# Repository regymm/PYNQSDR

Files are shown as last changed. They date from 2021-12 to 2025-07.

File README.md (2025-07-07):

## PYNQSDR

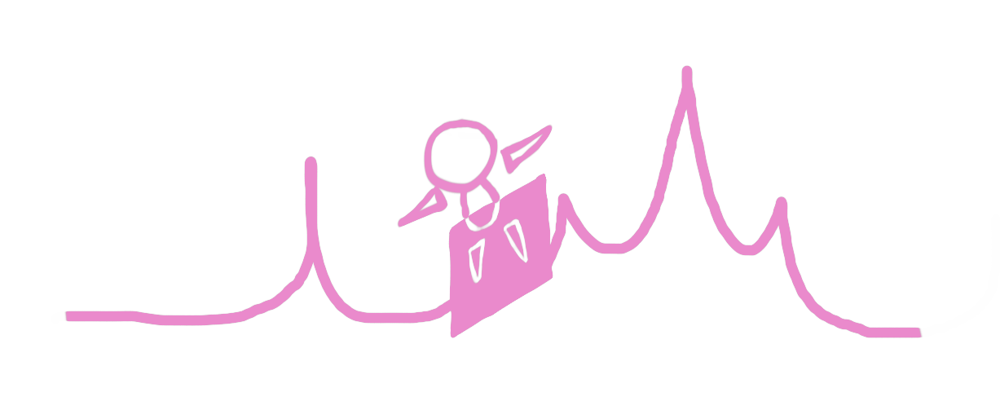
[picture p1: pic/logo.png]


### 🚀　**We're launching! Follow the updates on [Crowd Supply](https://www.crowdsupply.com/xtal-hart-tech/pynqsdr-hat)!**　🚀

PYNQ-Z1 + AD936X SDR platform and more. Openwifi & PlutoSDR capable. 

[KiCad files](./kicad) **|** [Design & future plan](Design.md) **|** [Talk on FOSDEM 2022](https://fosdem.org/2022/schedule/event/openwifipynqz1/) [Slides](doc/openwifi_pynqz1.pdf) **|** [Blog TBD] **|** [Quick start](Quickstart.md) **|** [EBAZSDR TBD]

**Boards are now for sale! Visit my store at [regymm's toy shop](https://regymm.github.io/regymm-toy-shop)!**

This project demonstrated that AD936X chip can combine with low-cost ZYNQ FPGA development boards, especially PYNQ-Z1, and run openwifi without problem. This can potentially become an extremely low-cost openwifi platform. And with extensions removed, you still have a PYNQ capable of any other serious ZYNQ projects. 

Going beyond PYNQ-Z1, this extension board can also combine with other hardware by easy 2-layer conversion board and provide even lower-cost platforms. 

#### Gallery

V1.1 board that works: 

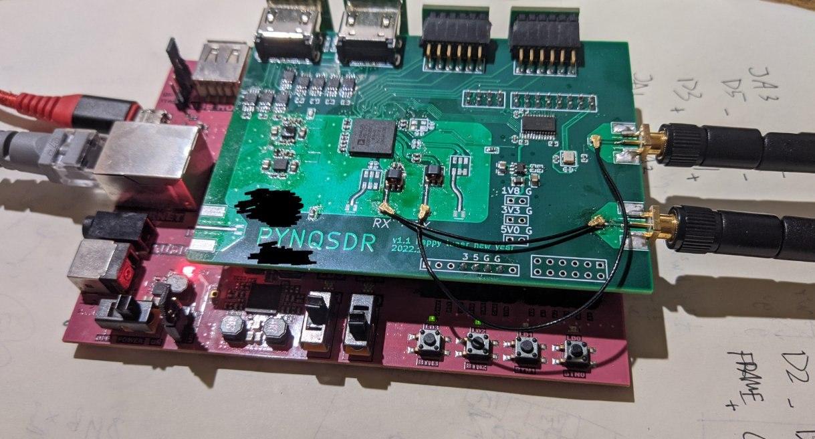
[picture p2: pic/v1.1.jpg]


Openwifi running on PYNQSDR: 

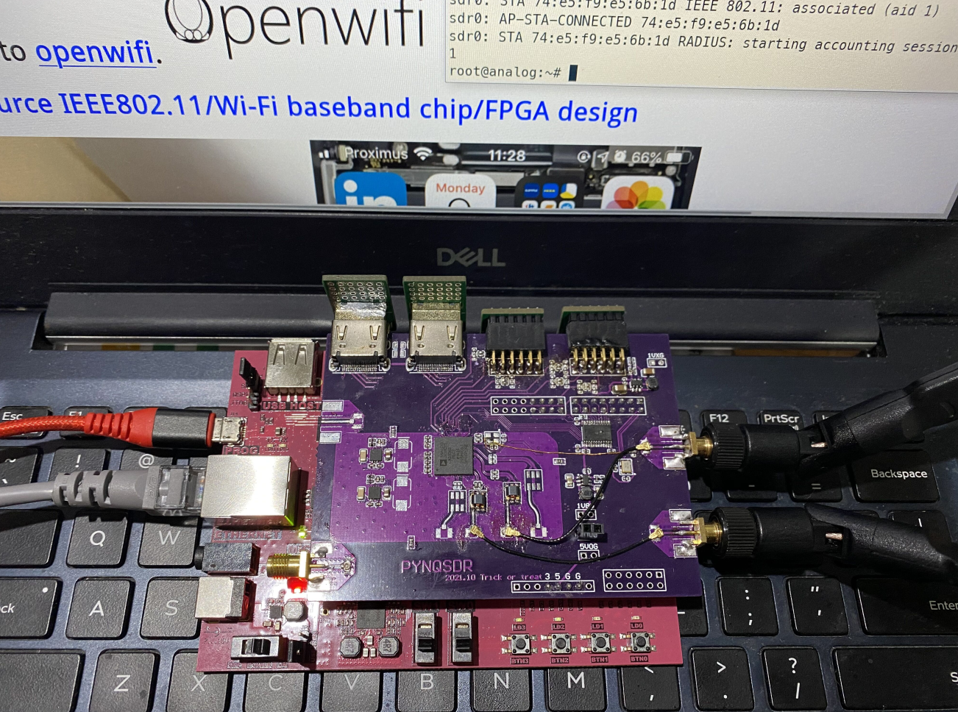
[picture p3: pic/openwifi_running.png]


Board anatomy: 

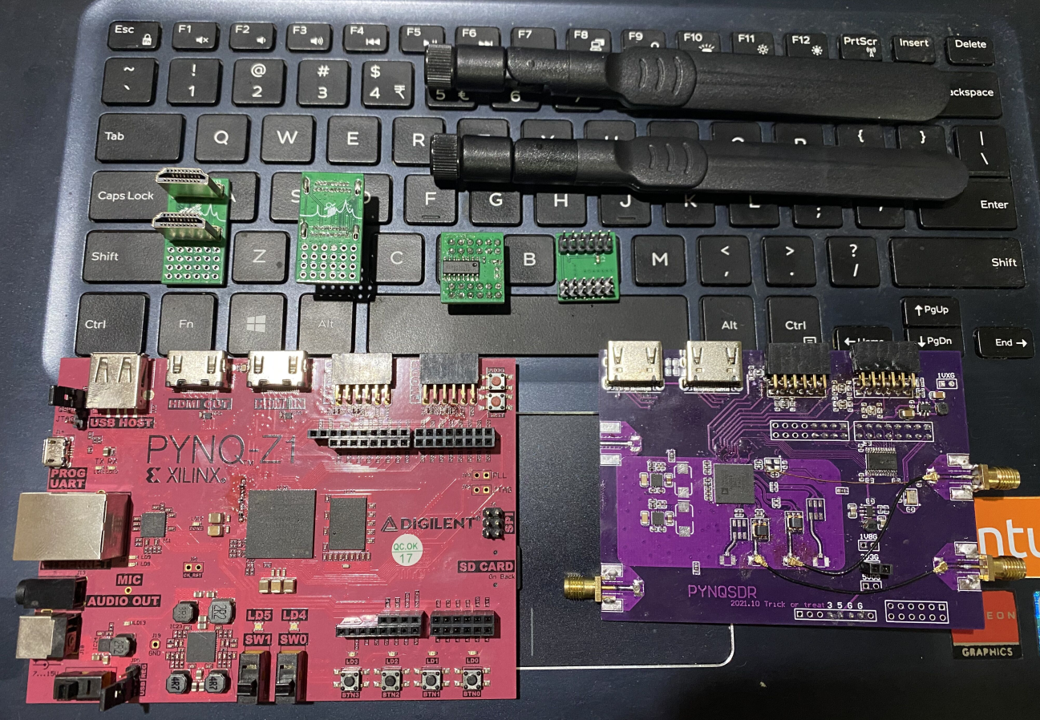
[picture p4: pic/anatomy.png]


#### Credits

Openwifi: https://github.com/open-sdr/openwifi

PlutoSDR: https://github.com/analogdevicesinc/plutosdr-fw

RF frontend PCB design based on https://github.com/kangyuzhe666/ZYNQ7010-7020_AD9363

Many online discussion groups also gave me a lot of help. 

#### License

GPLv3 for all board files. CC BY-SA for blog articles, documents, photos and the logo. Code are coming from different projects and should remain their original licenses.

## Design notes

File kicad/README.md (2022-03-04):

#### PYNQSDR KiCad hardware

pynqsdr: main board, converted from Altium so expect small problems. KiCad nighty required. [Schematics PDF](./pynqsdr.pdf)

br1: HDMI and PMOD direct-connect bridge. 

br2: PMOD bridge with LVDS driver DS90LV047A or SN65LVDS047A. Need 2 of this in initial release and current release(v1.1). 

br3: HDMI bridge with LVDS receiver DS90LVDS048A and PMOD direct-connect. 

br4: HDMI bridge with 4x LVDS to CML translator SN65CML100. Need 2 of this in inital release. 

br5: HDMI bridge with crossing and PMOD direct-connect bridge. 

**v1.1** release requirement: two HDMI direct-connect (br1), two DS90LVDS047A (br2)

**Initial** release requirement: two 4x SN65CML100 (br4), two DS90LVDS047A (br2)

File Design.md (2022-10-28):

#### Design

*Maybe you should first have a look at AD9363 + ZYNQ schematics of [PlutoSDR](https://wiki.analog.com/_media/university/tools/pluto/hacking/plutosdr_schematic_revd_0.1.pdf), [ANTSDR](https://github.com/MicroPhase/antsdr-fw/blob/master/schematic/ant_e310_Public.pdf), and [kangyuzhe666's SDR](https://github.com/kangyuzhe666/ZYNQ7010-7020_AD9363).*

A series of "hacking" is required to get things work. 

- AD936X run on 1.8 V or 2.5 V, while most FPGA boards have VCCIO 3.3 V
  - Use level converters like SN74AX8T245. Changing VCCIO is not plausible because USB and ETH PHY need 3.3 V
- Wiring is both poor and long on FPGA boards
  - So have to use LVDS mode. Openwifi needs LVDS anyways
  - Have to stick to 1RX 1TX. But that's enough for most applications
- But ZYNQ with 3.3 V HP VCCIO can't run LVDS
  - For receiving, HDMI can run TMDS_33. So re-drive using SN65CML100 -- NO change on PYNQ-Z1
    - Can also change 50 R pullup to 100 R series termination and directly receiving LVDS
    - Can also remove 50 R pullup and use DS90LVDS048A receiver
  - For sending, I use single-ended output on FPGA, and convert these to LVDS using DS90LVDS047
- PMOD can't run high speed
  - Yet it can run at 80 MHz (40 M sampling rate 1rx-1tx), enough for openwifi, dump1090, and everything else I tried
  - Optionally remove TVS diodes and 200 ohm series resistors, can run at 120 MHz (~61.44 M sampling rate 1rx-1tx)
- Board shape is strange...
  - Small connectors on PMOD/HDMI side is required
  - I'm worried about mechanical strains caused by HDMI bridges, so using short HDMI cables is being considered. 
- Hand-solder BGA?
  - Heatgun, soldering iron, solder paste, flux are enough, it's really not that hard
  - **warning**: Boards after SMT assembly will suffer oxidation when re-flowing, so ordering SMT assembly w/o the BGA chip then manually solder the BGA may not work well

#### Future plan

V1.2 seems good and will be for sale soon. Another batch(v1.2.1) with minor modification will come soon. 

...

Another 5 fabricated and proved to be fine. Another batch(v1.2) coming soon. 

...

Boards version 1.1 have been made and manually assembled using 1.0's material. It works fine, so another batch of 5 will be made in late Feb. 2022. 

...

Boards version 1.0 suffered BGA soldering problems because they have been re-flowed during STM assembly. 

...

Since I'm confident unmodified PYNQ-Z1 can make it, board version 1.0 will be designed and sent to fabrication and SMT assembly before Dec 31, 2021. 5 boards are to be made. 

If the 5 boards turn to be OK, more will be coming. 

---

Design "explained"(initial testing version, **deprecated**):

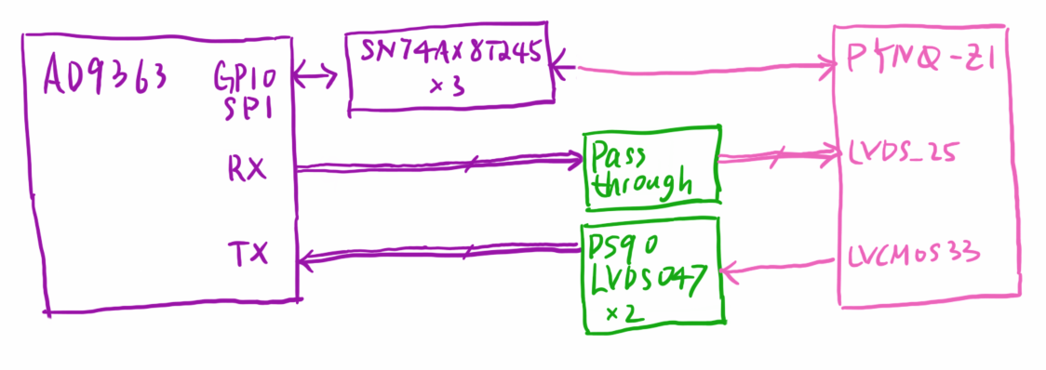
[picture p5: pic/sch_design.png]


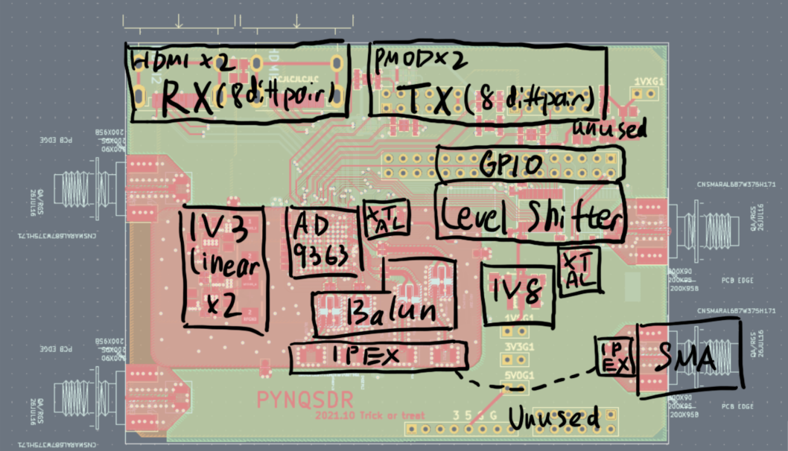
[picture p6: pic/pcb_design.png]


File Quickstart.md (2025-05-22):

### PYNQSDR Quick Start

#### Pre-built images

Currently hosted on my website http://152.70.101.209/

#### Board 

Plug extension boards together, make sure the PMOD plugins are in correct direction -- the 3V3/GND is on the left and IC is on the right: 

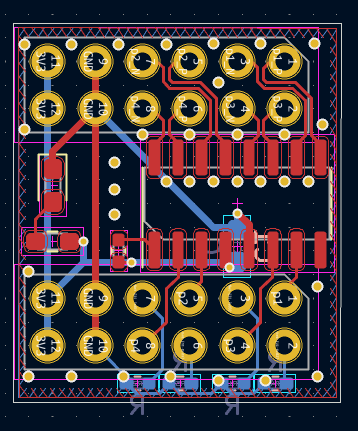
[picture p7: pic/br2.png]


Setup PYNQ-Z1 jumpers to boot from SD card. Use a stable power supply and avoid using USB hubs. Use a good ethernet cable. 

#### Firmware

SD card's boot partition contains boot files, for PlutoSDR, put these into root directory:

```
uEnv.txt -- u-boot loading script
boot.bin -- ZYNQ FSBL including bitstream
uImage -- Linux kernel
devicetree.dtb -- Linux device tree
uramdisk.image.gz -- Linux root directory
```

For openwifi(all of these are different from the Pluto ones!): 

```
uEnv.txt
boot.bin
uImage
devicetree.bin
```

#### Power on

Turn on the power, you'll see the red power LED on -- if this doesn't happen, immediately power off and check your board -- there's probably a short. After ~0.5s LD0-LD3 will have some action after bitstream is loaded. PlutoSDR: among the 4 green LEDs, some is brightly on. Openwifi: some are slightly on(as a simple check, don't rely on this). 

#### Connect

*Pluto*

Linux terminal on USB serial port 115200 baud, root password is `analog`. Board IP will be 192.168.1.10 so set host IP to 192.168.1.2 or so. 

*Openwifi*

Set host ethernet IP to 192.168.10.1, board IP will be 192.168.10.122, ssh into board, username: root, password: `openwifi`. USB serial port has early boot message but will stop after kernel booting(to be solved) so use SSH. 

It's recommended to assign 2 IP addresses(192.168.10.1 and 192.168.1.2 at the same time) to a spare ethernet port. 

#### Pluto

This blog for setup. 

https://regymm.github.io/MyBlog/experience/2022/01/13/plutosdr-setup.html

Since ILA(Vivado internal logic analyzer) corresponding to the pre-built firmware is also included in the downloadable Vivado project, you can open hardware manager in Vivado, the ILA will automatically pop up. 

#### Openwifi 

Manually tune RX/TX: 

```
~/tune.sh
```

`dmesg` to check tune OK: 

```
SAMPL CLK: 40000000 tuning: RX
  0:1:2:3:4:5:6:7:8:9:a:b:c:d:e:f:
0:o o o o o o o o O o o o o o o o 
1:o o o o o # # # # # # # # # # # 
SAMPL CLK: 40000000 tuning: TX
  0:1:2:3:4:5:6:7:8:9:a:b:c:d:e:f:
0:# # # # # # # # # # # # # # # # 
1:# # # # # # # o o o o O o o o o
```

The script is just: 

```
cd /sys/bus/iio/devices/iio\:device1
echo 40000000 > in_voltage_sampling_frequency

cd /sys/kernel/debug/iio/iio\:device1/
echo 0 > adi,digital-interface-tune-skip-mode 
echo 0 3 > digital_tune

dmesg
```

Start wifi: 

`~/openwifi/fosdem-11ag.sh`

*If you are building firmware youself: my board seems to need 10 dB TX attenuation for best transmission, so `#define AD9361_RADIO_ON_TX_ATT 10000` in sdr.h*

#### Troubleshooting

Just contact me...

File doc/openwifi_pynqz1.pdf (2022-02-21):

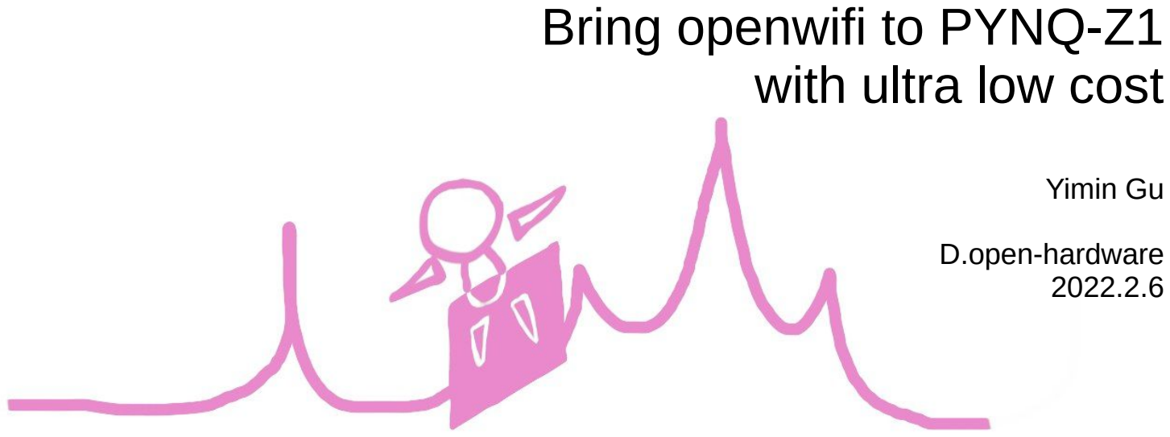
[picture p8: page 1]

## Bring openwifi to PYNQ-Z1

## with ultra low cost

Yimin Gu

D.open-hardware
2022.2.6

## About Me(@regymm)

- Physics undergrad finished last year
- FPGA, PCB design, RISC-V, osdev, scavenge & tweak, NetHack, webcomic…

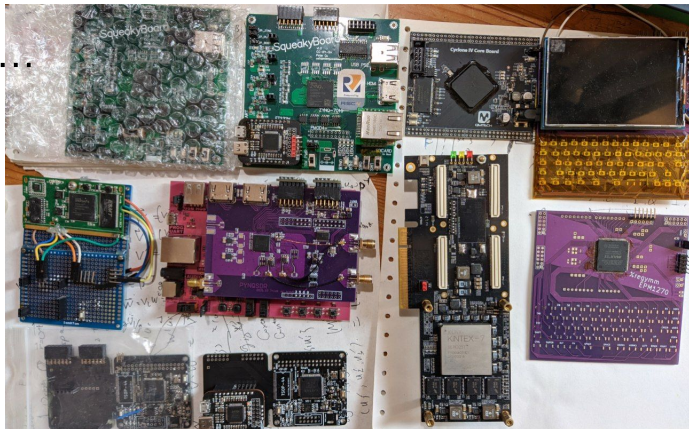
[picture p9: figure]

- SDR: too interesting to ignore…

## Today

- Background that I don’t understand much
- My work: openwifi to PYNQ-Z1
- About “modern” hardware DIY at home

## Background

- Xilinx ZYNQ + ADI AD936X is very capable
- 7010 CLG225 + AD9363 => PlutoSDR
- 7020 CLG400 above + AD9364 => openwifiSp

## Background

- Price is a problem
– | Zedboard + FMCOMMS3 $1300
– | ADRV9364-Z7020 + Carrier $800
– | ANTSDR E310 $300
– | PlutoSDR $150

## PYNQSDR

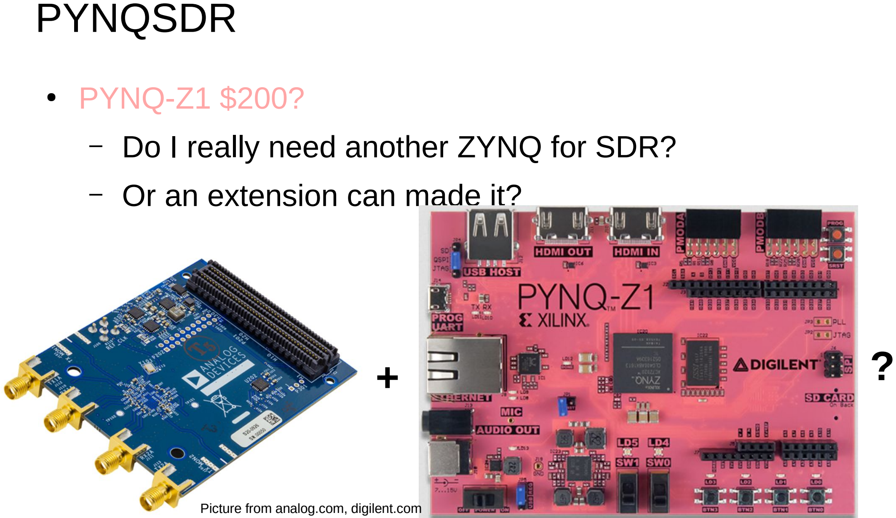
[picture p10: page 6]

- PYNQ-Z1 $200?
– | Do I really need another ZYNQ for SDR?
– | Or an extension can made it?
+ | ?

Picture from analog.com, digilent.com

## PYNQSDR

- AD936X requirements
– | ~21 GPIO at 1.8V/2.5V
– | 16 LVDS diffpairs @ ~120 MHz DDR
- What PYNQ-Z1 has
– | ~49 GPIO at 3.3V, poorly routed
– | 2x HDMI, each 4 diffpairs, 50R* pullup terminaion
– | 2x PMOD, each 4 diffpairs w/ 200R* series and ESD diodes*
| *can be removed/hacked but I don’t want to

## PYNQSDR

- AD936X requirements
– | ~21 GPIO at 1.8V/2.5V
– | 16 LVDS diffpairs @ ~40 MHz DDR
- What PYNQ-Z1 has
– | ~49 GPIO at 3.3V, poorly routed
– | 2x HDMI, each 4 diffpairs, 50R* pullup terminaion
– | 2x PMOD, each 4 diffpairs w/ 200R* series and ESD diodes*
| *can be removed/hacked but I don’t want to

3.3V to 1.8V

LVDS to TMDS(FPGA RX)

LVDS to single-ended(TX)

Hack 9363 to 9364 is bad but...

## PYNQSDR

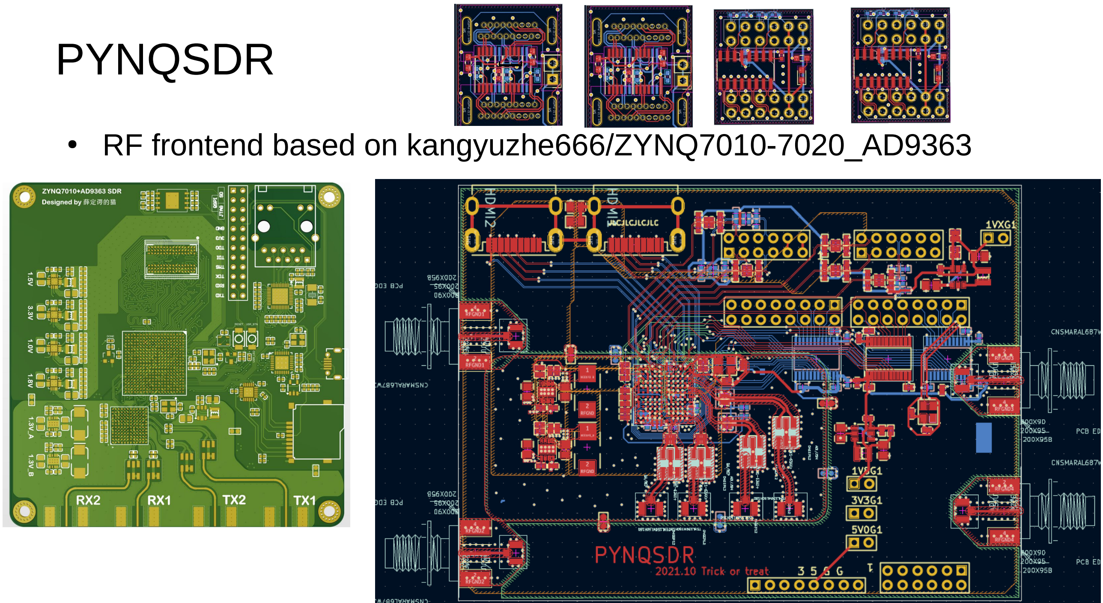
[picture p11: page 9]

- RF frontend based on kangyuzhe666/ZYNQ7010-7020_AD9363

[

## PYNQSDR

- Firmware porting based on ANTSDR

– checklist: adi-hdl(IO, ps7, xdc), u-boot, kernel, dts

- Stick to 1 RX 1TX mode(TX can run ~50 MHz DDR at most)
- … and afaik everything works
– | Openwifi 5G hotspot/client
– | GQRX FM
– | ADS-B

## PYNQSDR

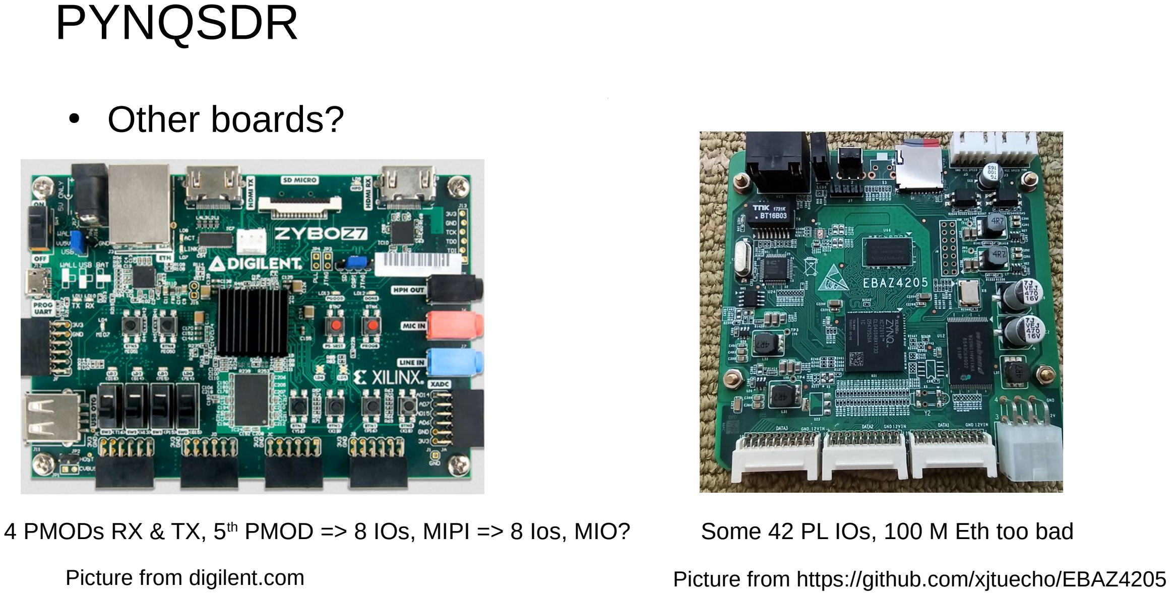
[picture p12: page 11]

- Other boards?

Picture from digilent.com

4 PMODs RX & TX, 5th PMOD => 8 IOs, MIPI => 8 Ios, MIO?

Picture from https://github.com/xjtuecho/EBAZ4205

Some 42 PL IOs, 100 M Eth too bad

## About “modern” HW DIY at home

- Manufacture at JLCPCB/… leaded 4-layer 0.8mm BGA should be affordable
- “Refurbished” chips on Taobao/Aliexpress

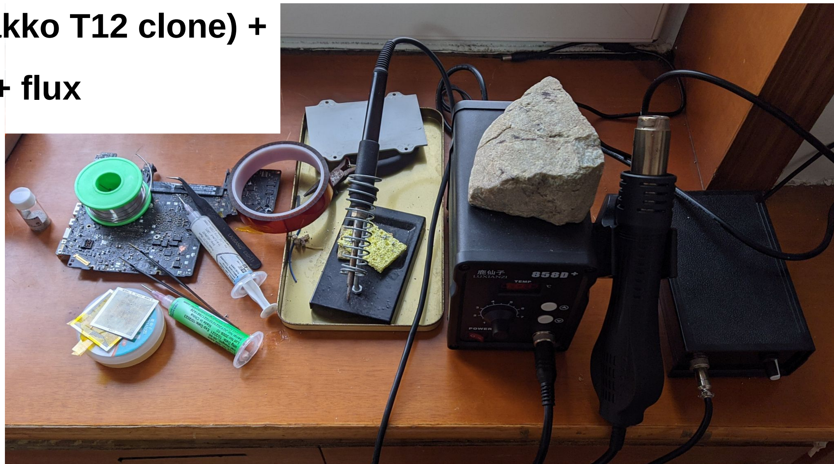
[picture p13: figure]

- Soldering iron(936 or hakko T12 clone) +

heatgun + solder paste + flux

## About “modern” HW DIY at home

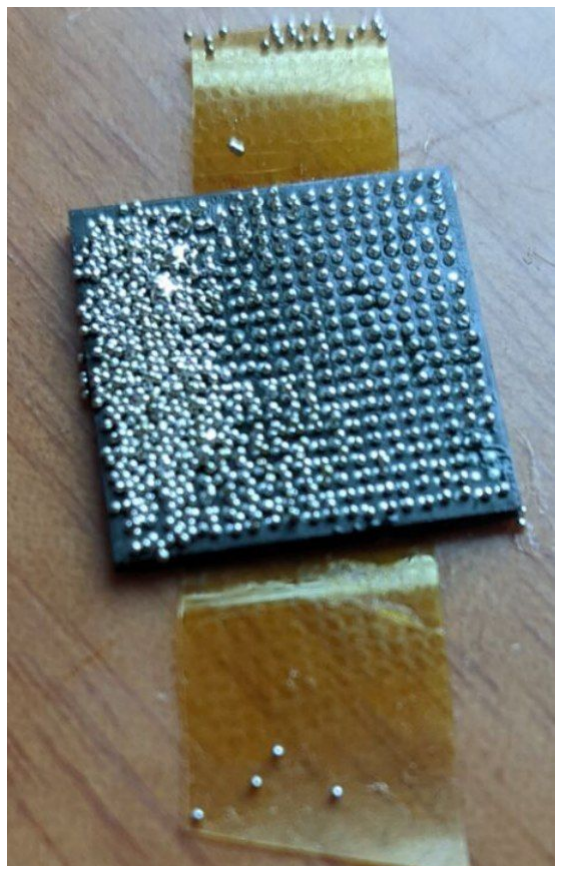
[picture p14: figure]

- BGA?

## Thanks!

- Dr. Jiao’s nice help & invitation to FOSDEM
- kangyuzhe666’s SDR
- Various discussion groups

Q & A

Contact

– | GitHub repo for PYNQSDR: github.com/regymm/PYNQSDR
– | My Twitter: @regymm0
– | My Telegram: @regymm0 Channel: t.me/xtalhart

*For later viewers: it’s recommended to watch the talk, many important stuffs are not shown in this slides

*Proudly made with LibreOffice

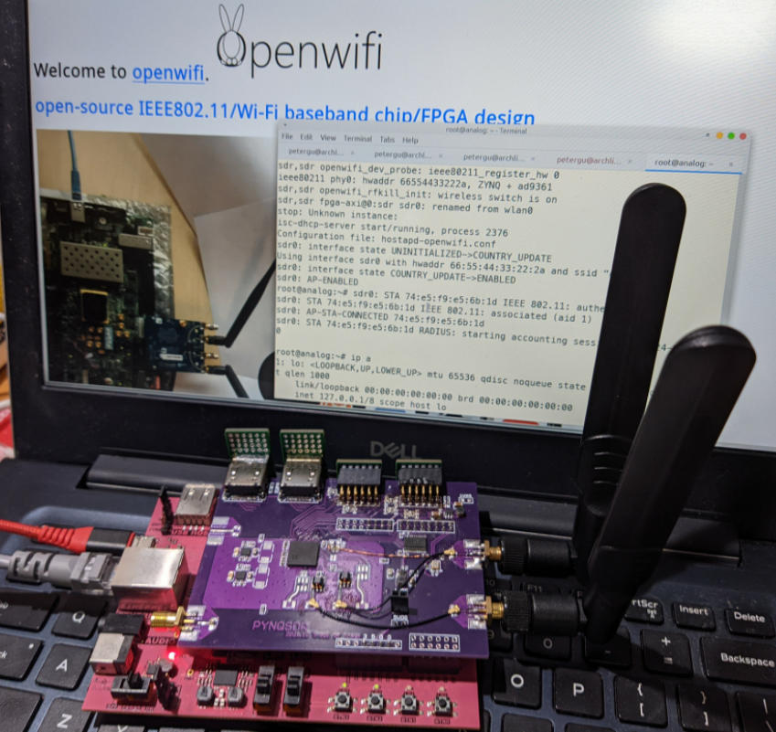
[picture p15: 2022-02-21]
pic/pic2.png

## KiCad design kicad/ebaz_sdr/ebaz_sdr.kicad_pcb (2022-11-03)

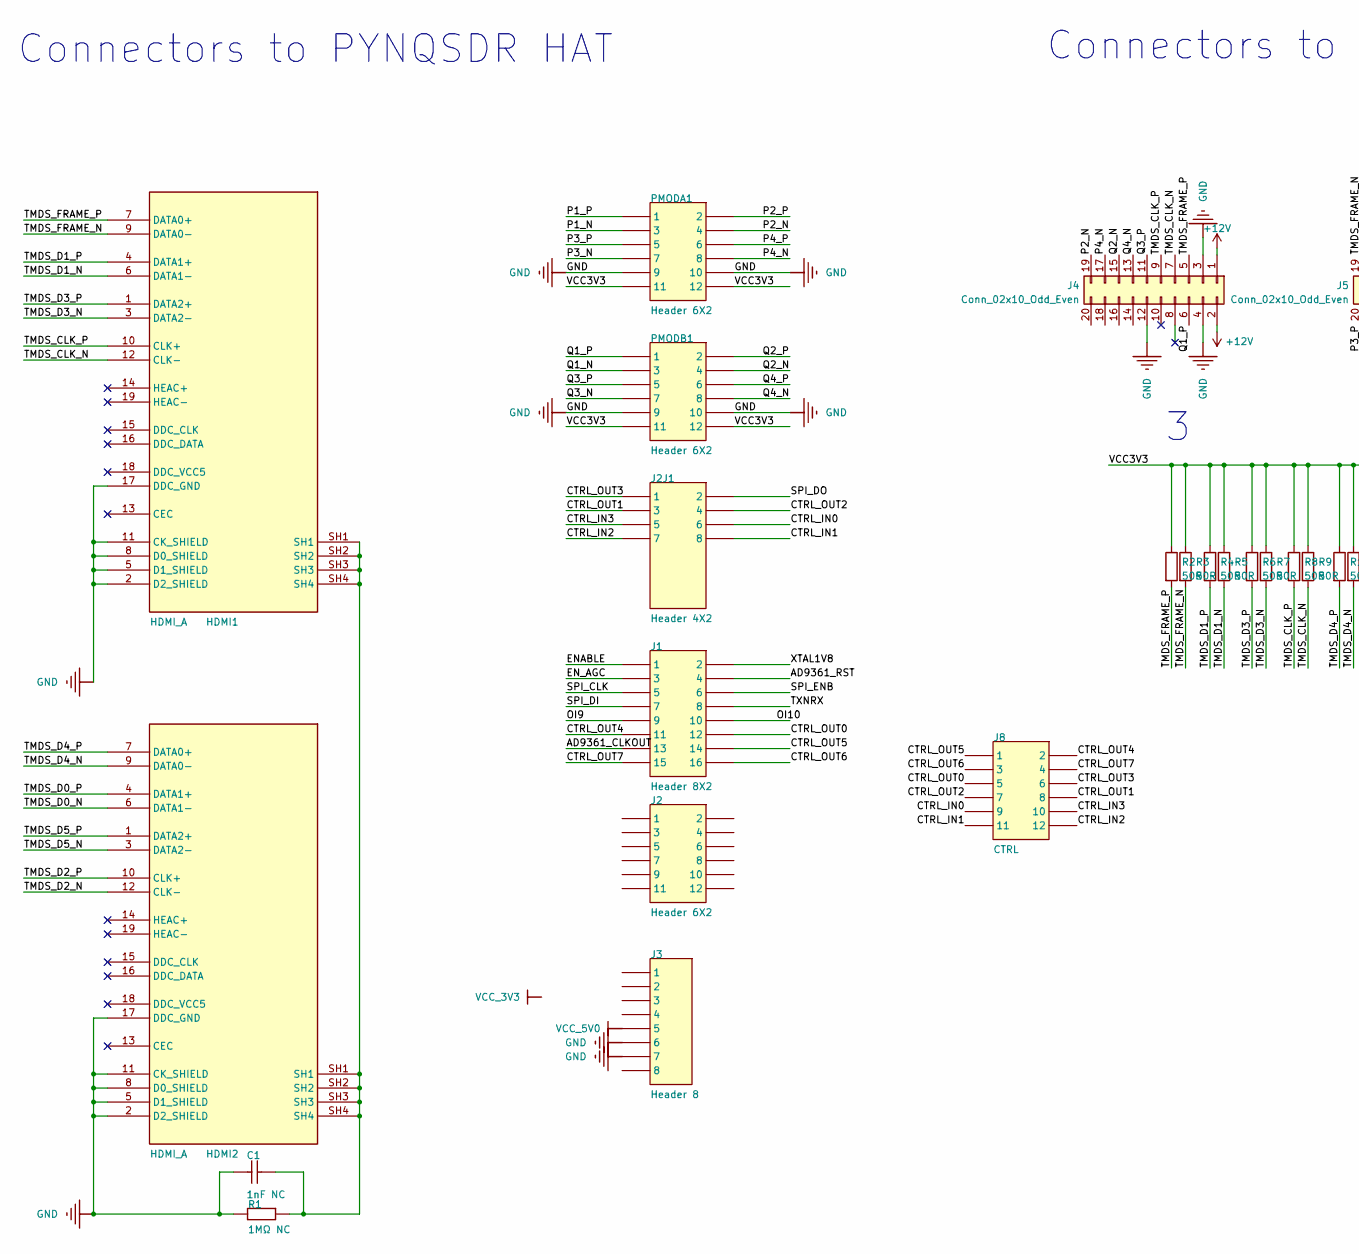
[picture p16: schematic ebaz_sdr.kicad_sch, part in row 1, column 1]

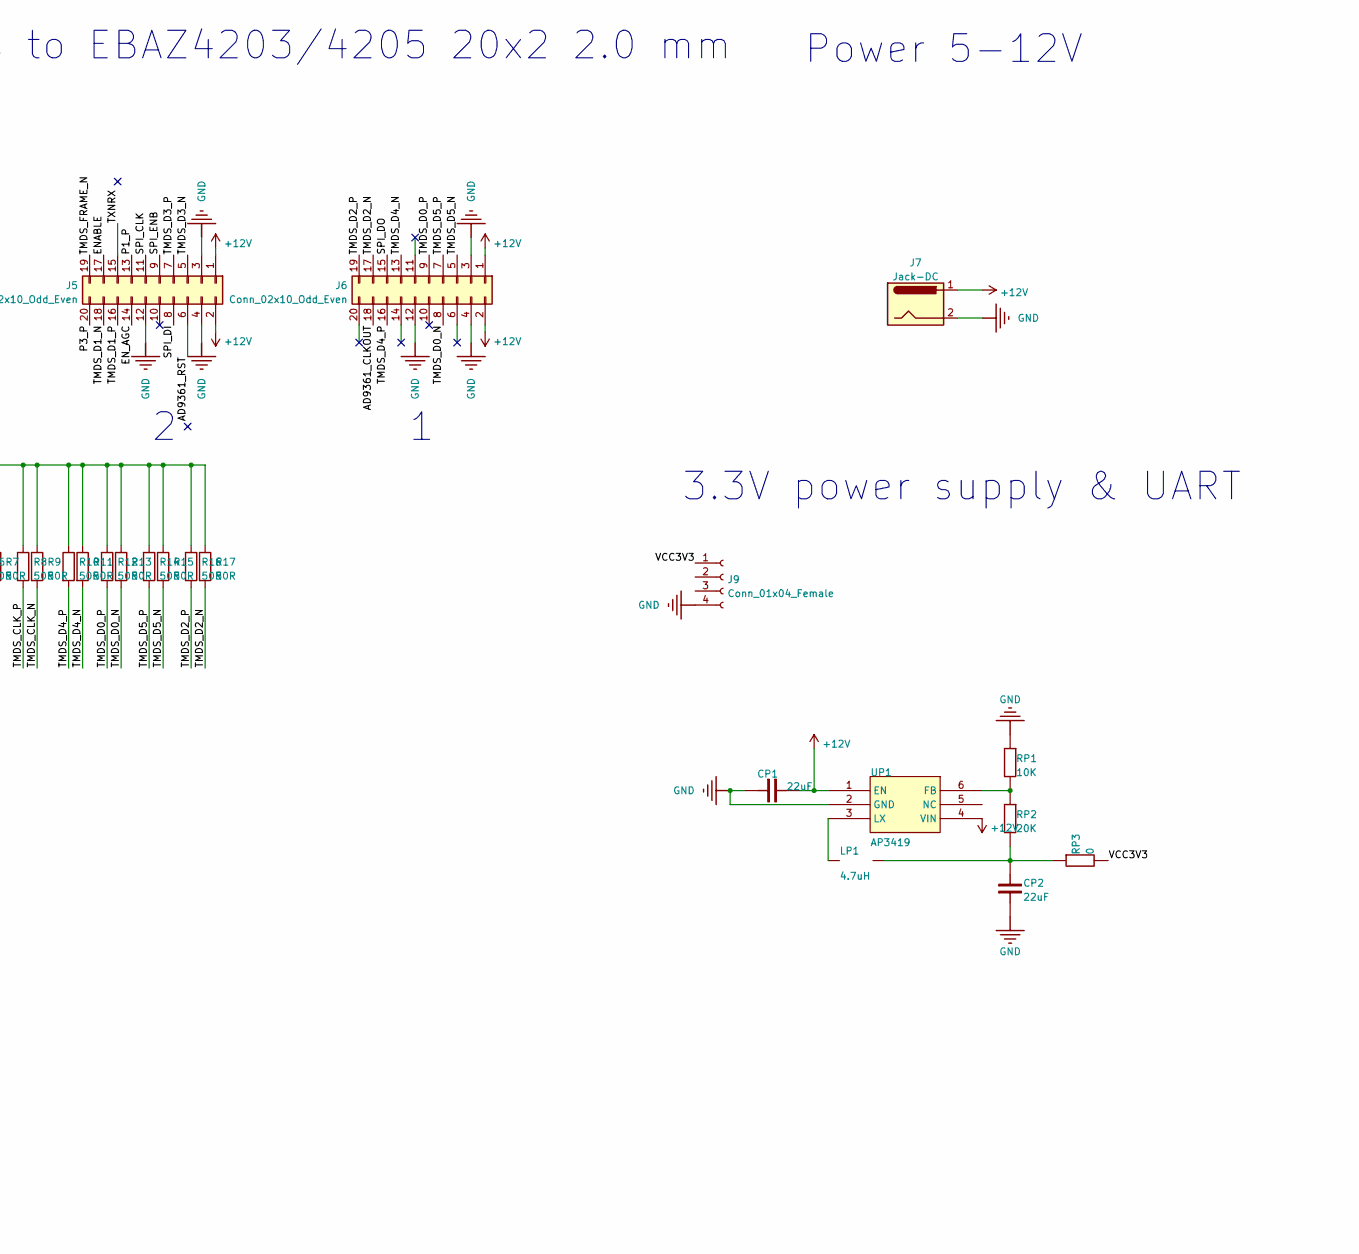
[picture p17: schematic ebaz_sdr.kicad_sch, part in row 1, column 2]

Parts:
C1: 1nF NC; R_0603_1608Metric_Pad0.98x0.95mm_HandSolder
CP1, CP2: 22uF; LC-0805_C
HDMI1, HDMI2: HDMI_A
J1: Header 8X2; HDR2X8
J2: Header 6X2; HDR2X6
J2J1: Header 4X2; HDR2X8
J3: Header 8; HDR1X8
J4, J5, J6: Conn_02x10_Odd_Even; PinSocket_2x10_P2.00mm_Horizontal
J7: Jack-DC; BarrelJack_Wuerth_6941xx301002
J8: CTRL; HDR2X6
J9: Conn_01x04_Female; PinHeader_1x04_P2.54mm_Vertical
LP1: 4.7uH; L1008
PMODA1: Header 6X2; HDR2X6
PMODB1: Header 6X2; HDR2X6
R1: 1MΩ NC; R_0603_1608Metric_Pad0.98x0.95mm_HandSolder
R2, R3, R4, R5, R6, R7, R8, R9, R10, R11, R12, R13, R14, R15, R16, R17: 50R; R_0402_1005Metric_Pad0.72x0.64mm_HandSolder
RP1: 10K; LC-0402_R
RP2: 20K; LC-0402_R
RP3: 0; LC-0402_R
UP1: AP3419

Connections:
+12V: CP1.2, J4.1, J4.2, J5.1, J5.2, J6.1, J6.2, J7.1, UP1.1 (EN), UP1.4 (VIN)
/AD9361_CLKOUT: J1.13, J6.18
/AD9361_RST: J1.4, J5.6
/CTRL_IN0: J2J1.6, J8.9
/CTRL_IN1: J2J1.8, J8.11
/CTRL_IN2: J2J1.7, J8.12
/CTRL_IN3: J2J1.5, J8.10
/CTRL_OUT0: J1.12, J8.5
/CTRL_OUT1: J2J1.3, J8.8
/CTRL_OUT2: J2J1.4, J8.7
/CTRL_OUT3: J2J1.1, J8.6
/CTRL_OUT4: J1.11, J8.2
/CTRL_OUT5: J1.14, J8.1
/CTRL_OUT6: J1.16, J8.3
/CTRL_OUT7: J1.15, J8.4
/ENABLE: J1.1, J5.17
/EN_AGC: J1.3, J5.14
/OI9: J1.9
/OI10: J1.10
/P1_N: PMODA1.3
/P1_P: J5.13, PMODA1.1
/P2_N: J4.19, PMODA1.4
/P2_P: PMODA1.2
/P3_N: PMODA1.7
/P3_P: J5.20, PMODA1.5
/P4_N: J4.17, PMODA1.8
/P4_P: PMODA1.6
/Q1_N: PMODB1.3
/Q1_P: J4.6, PMODB1.1
/Q2_N: J4.15, PMODB1.4
/Q2_P: PMODB1.2
/Q3_N: PMODB1.7
/Q3_P: J4.11, PMODB1.5
/Q4_N: J4.13, PMODB1.8
/Q4_P: PMODB1.6
/SPI_CLK: J1.5, J5.11
/SPI_DI: J1.7, J5.8
/SPI_DO: J2J1.2, J6.15
/SPI_ENB: J1.6, J5.9
/TMDS_CLK_N: HDMI1.12 (CLK-), J4.7, R9.2
/TMDS_CLK_P: HDMI1.10 (CLK+), J4.9, R8.2
/TMDS_D0_N: HDMI2.6 (DATA1-), J6.8, R13.2
/TMDS_D0_P: HDMI2.4 (DATA1+), J6.9, R12.2
/TMDS_D1_N: HDMI1.6 (DATA1-), J5.18, R5.2
/TMDS_D1_P: HDMI1.4 (DATA1+), J5.16, R4.2
/TMDS_D2_N: HDMI2.12 (CLK-), J6.17, R17.2
/TMDS_D2_P: HDMI2.10 (CLK+), J6.19, R16.2
/TMDS_D3_N: HDMI1.3 (DATA2-), J5.5, R7.2
/TMDS_D3_P: HDMI1.1 (DATA2+), J5.7, R6.2
/TMDS_D4_N: HDMI2.9 (DATA0-), J6.13, R11.2
/TMDS_D4_P: HDMI2.7 (DATA0+), J6.16, R10.2
/TMDS_D5_N: HDMI2.3 (DATA2-), J6.5, R15.2
/TMDS_D5_P: HDMI2.1 (DATA2+), J6.7, R14.2
/TMDS_FRAME_N: HDMI1.9 (DATA0-), J5.19, R3.2
/TMDS_FRAME_P: HDMI1.7 (DATA0+), J4.5, R2.2
/TXNRX: J1.8, J5.15
/VCC3V3: J9.1, PMODA1.11, PMODA1.12, PMODB1.11, PMODB1.12, R2.1, R3.1, R4.1, R5.1, R6.1, R7.1, R8.1, R9.1, R10.1, R11.1, R12.1, R13.1, R14.1, R15.1, R16.1, R17.1, RP3.1
/XTAL1V8: J1.2
GND: C1.2, CP1.1, CP2.1, HDMI1.2 (D2_SHIELD), HDMI1.5 (D1_SHIELD), HDMI1.8 (D0_SHIELD), HDMI1.11 (CK_SHIELD), HDMI1.17 (DDC_GND), HDMI2.2 (D2_SHIELD), HDMI2.5 (D1_SHIELD), HDMI2.8 (D0_SHIELD), HDMI2.11 (CK_SHIELD), HDMI2.17 (DDC_GND), J3.6, J3.7, J4.3, J4.4, J4.12, J5.3, J5.4, J5.12, J6.3, J6.4, J6.12, J7.2, J9.4, PMODA1.9, PMODA1.10, PMODB1.9, PMODB1.10, R1.2, RP1.2, UP1.2 (GND)
unnamed: C1.1, HDMI1.SH1, HDMI1.SH2, HDMI1.SH3, HDMI1.SH4, HDMI2.SH1, HDMI2.SH2, HDMI2.SH3, HDMI2.SH4, R1.1
unnamed: CP2.2, LP1.2, RP2.1, RP3.2
unnamed: LP1.1, UP1.3 (LX)
unnamed: RP1.1, RP2.2, UP1.6 (FB)
VCC_5V0: J3.5

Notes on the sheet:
Power 5-12V
Connectors to EBAZ4203/4205 20x2 2.0 mm
Connectors to PYNQSDR HAT
3.3V power supply & UART
3 2 1

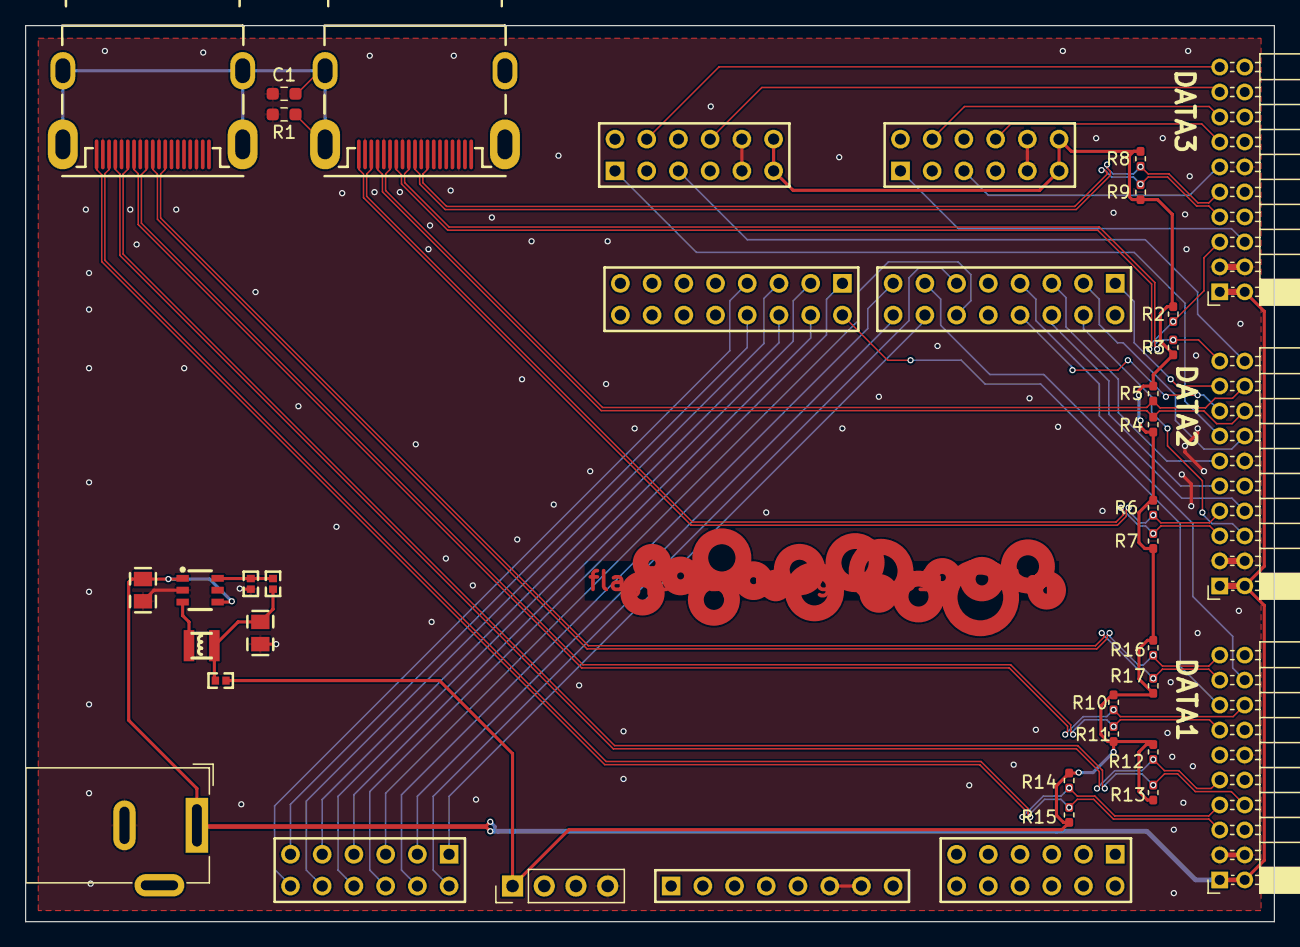
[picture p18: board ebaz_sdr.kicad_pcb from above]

Board: 2 copper layers, 100.0 x 71.8 mm, 39 parts (0 on the bottom side), 52 nets.

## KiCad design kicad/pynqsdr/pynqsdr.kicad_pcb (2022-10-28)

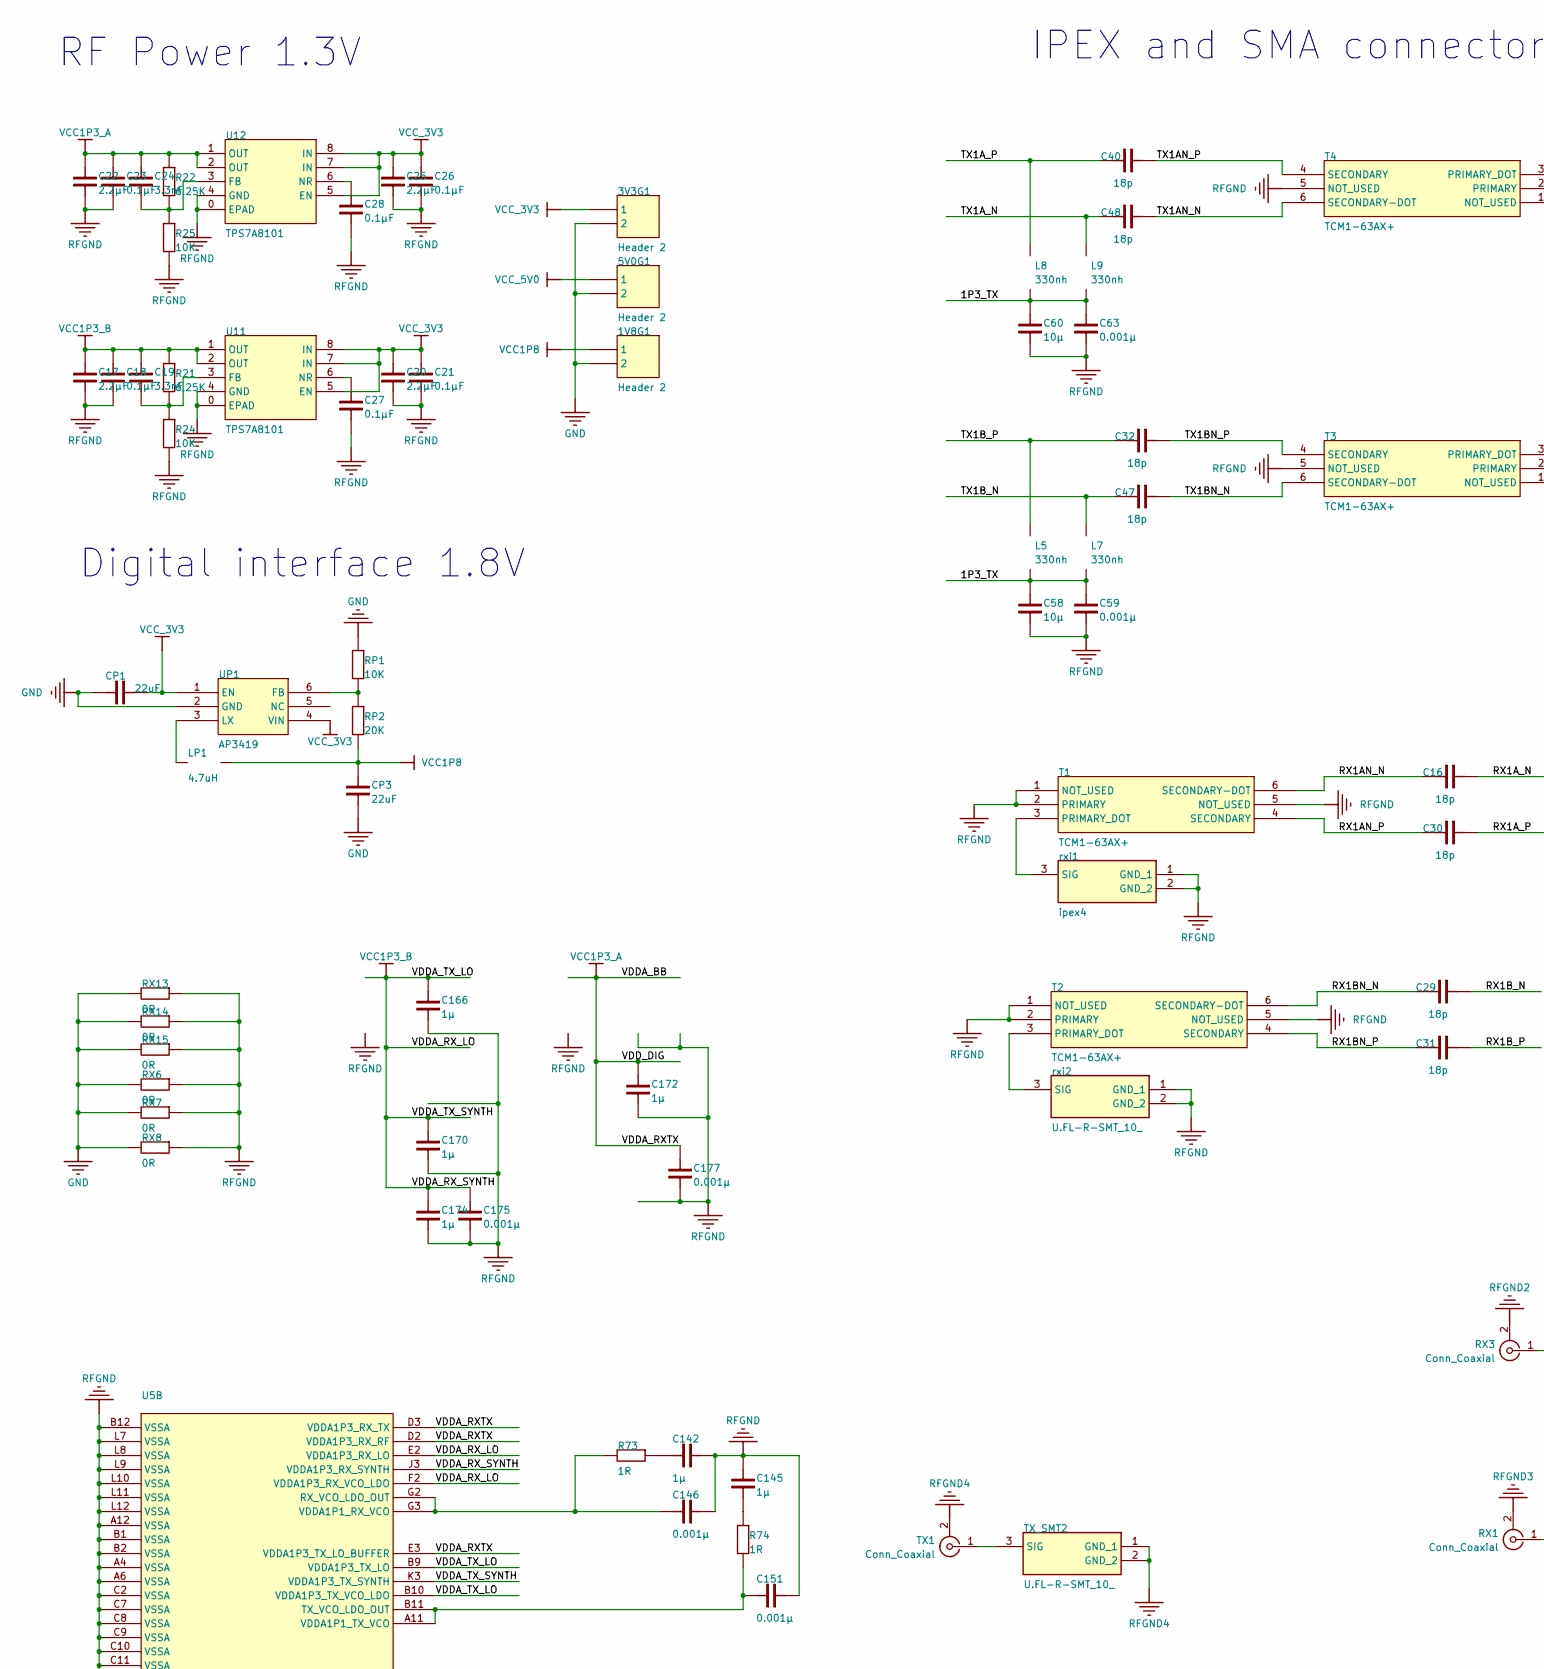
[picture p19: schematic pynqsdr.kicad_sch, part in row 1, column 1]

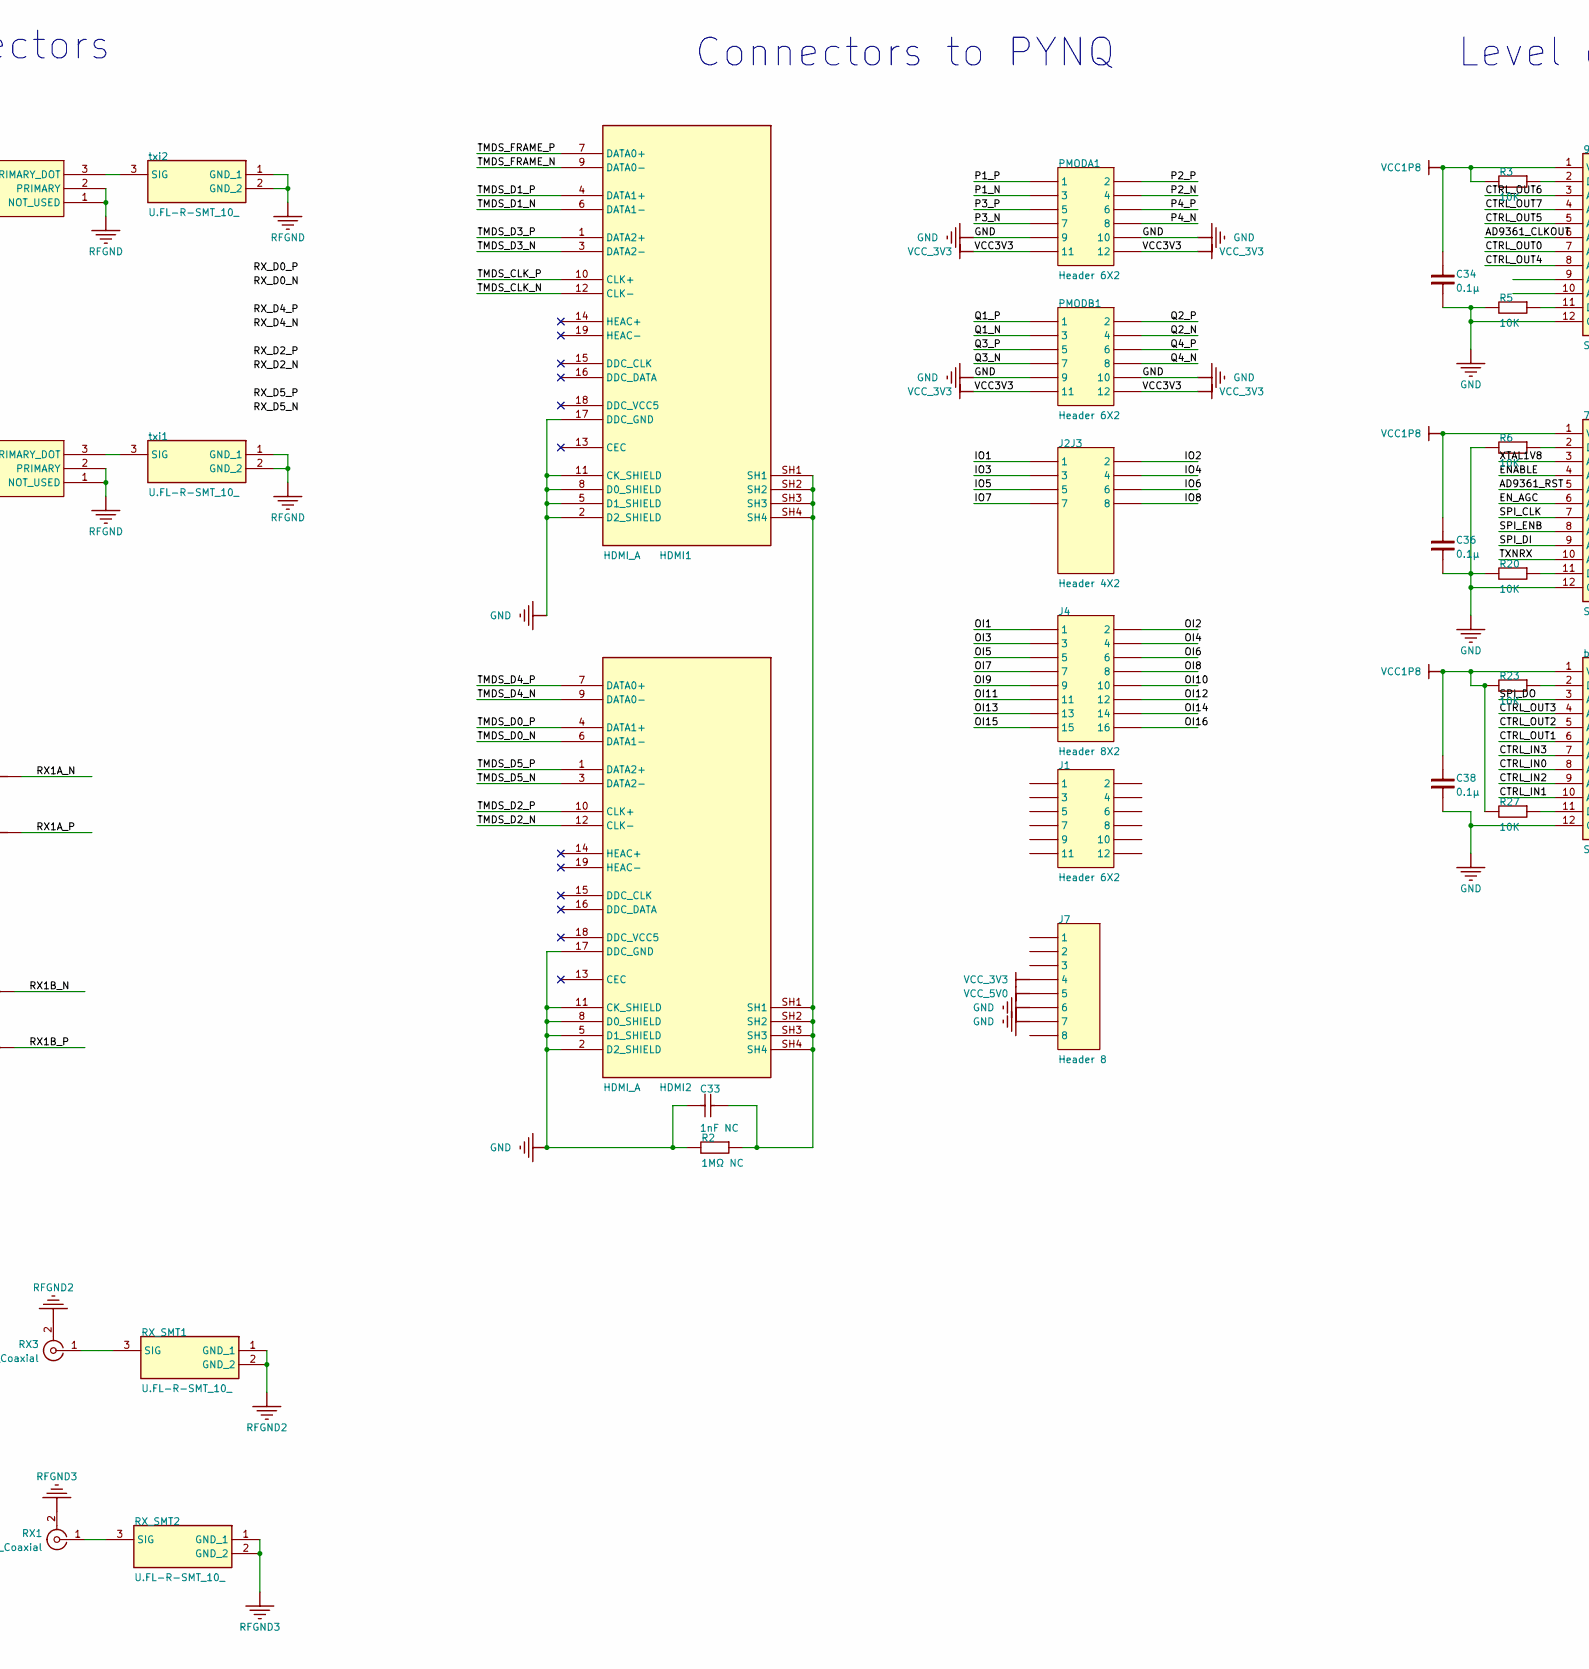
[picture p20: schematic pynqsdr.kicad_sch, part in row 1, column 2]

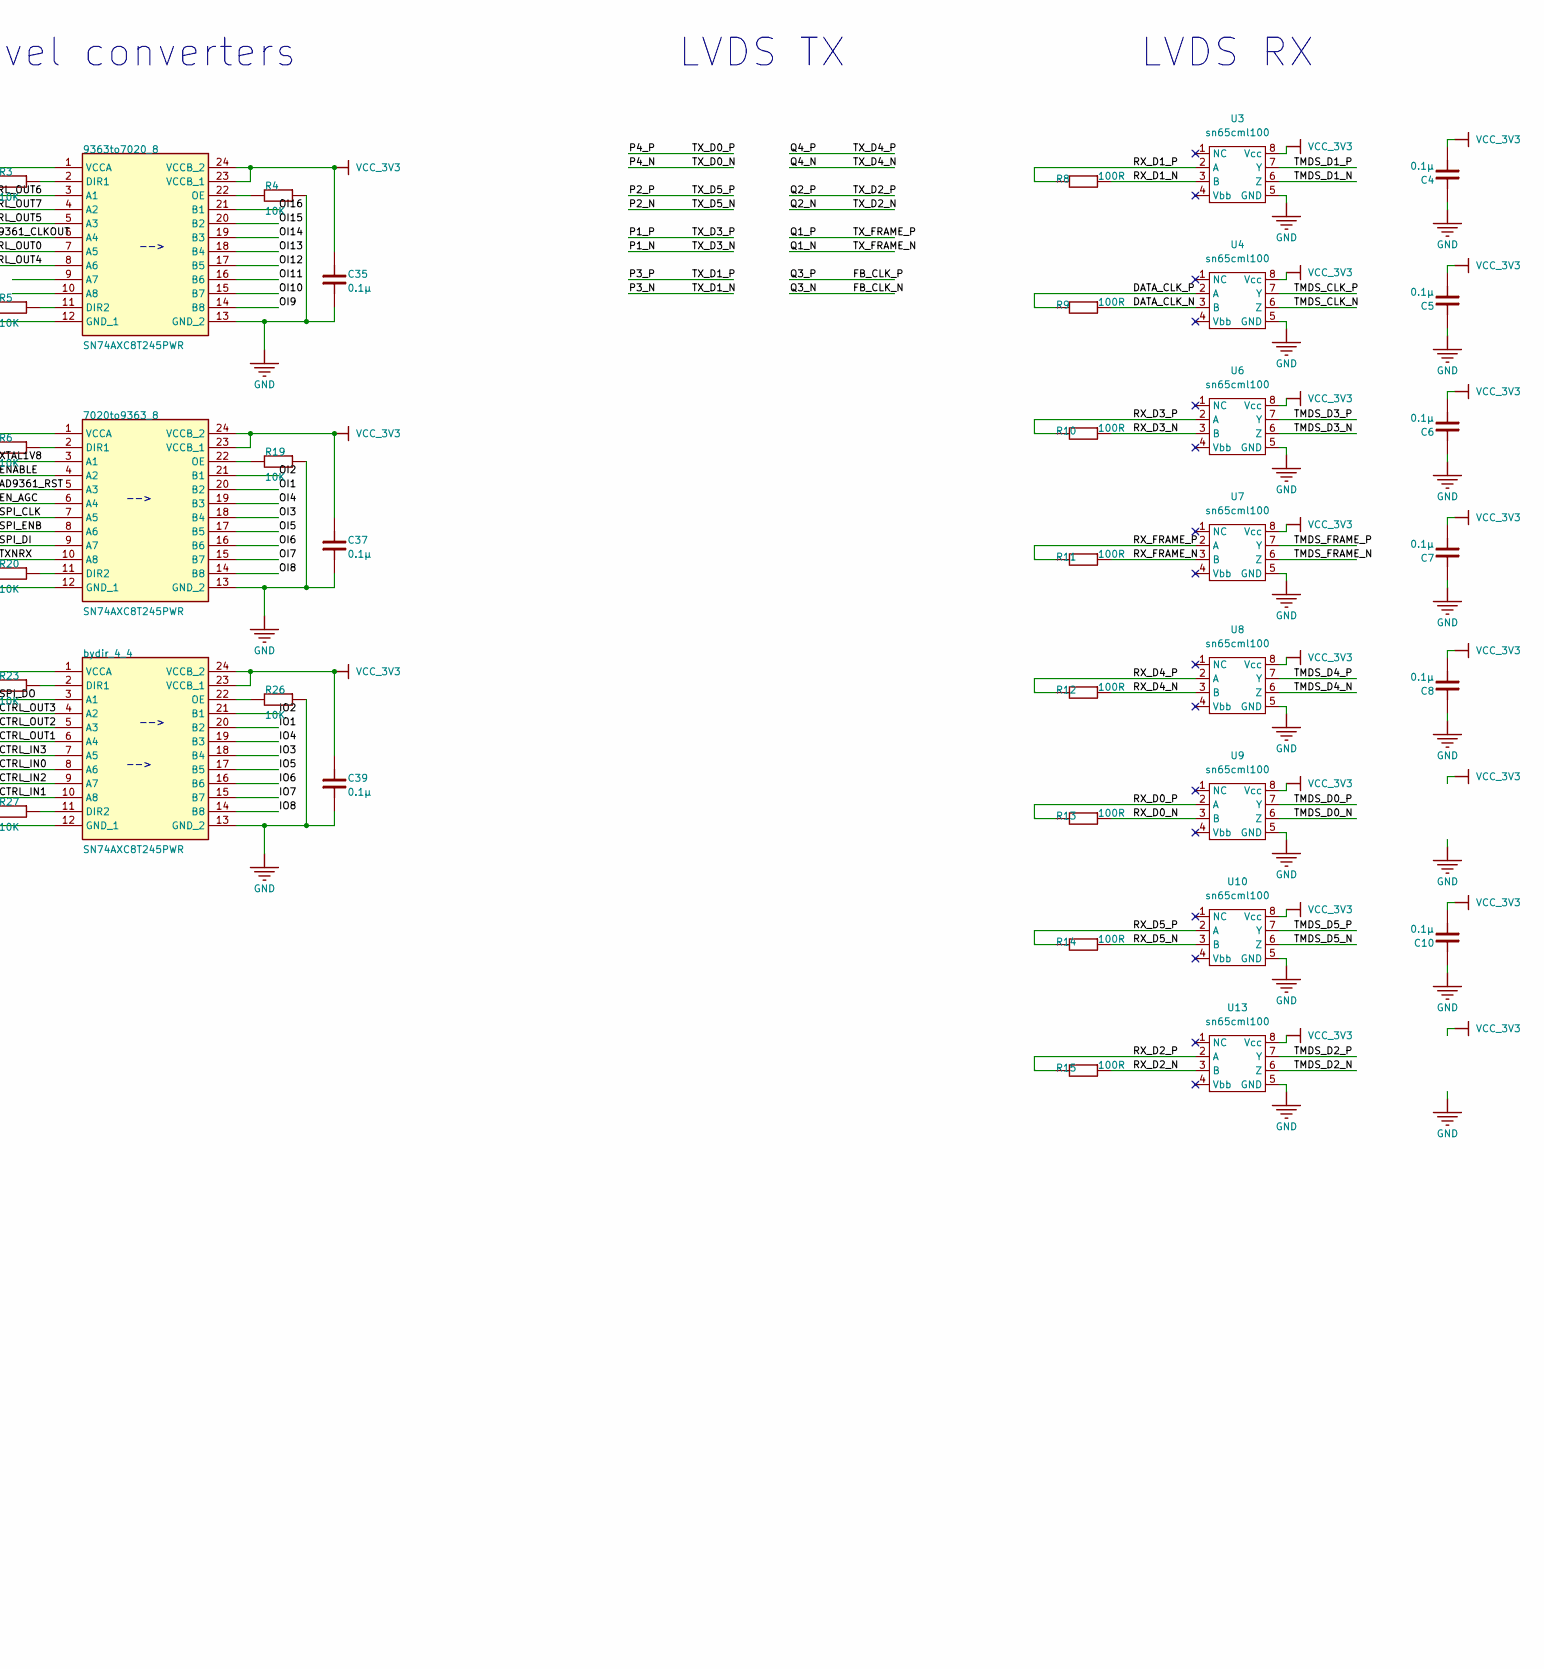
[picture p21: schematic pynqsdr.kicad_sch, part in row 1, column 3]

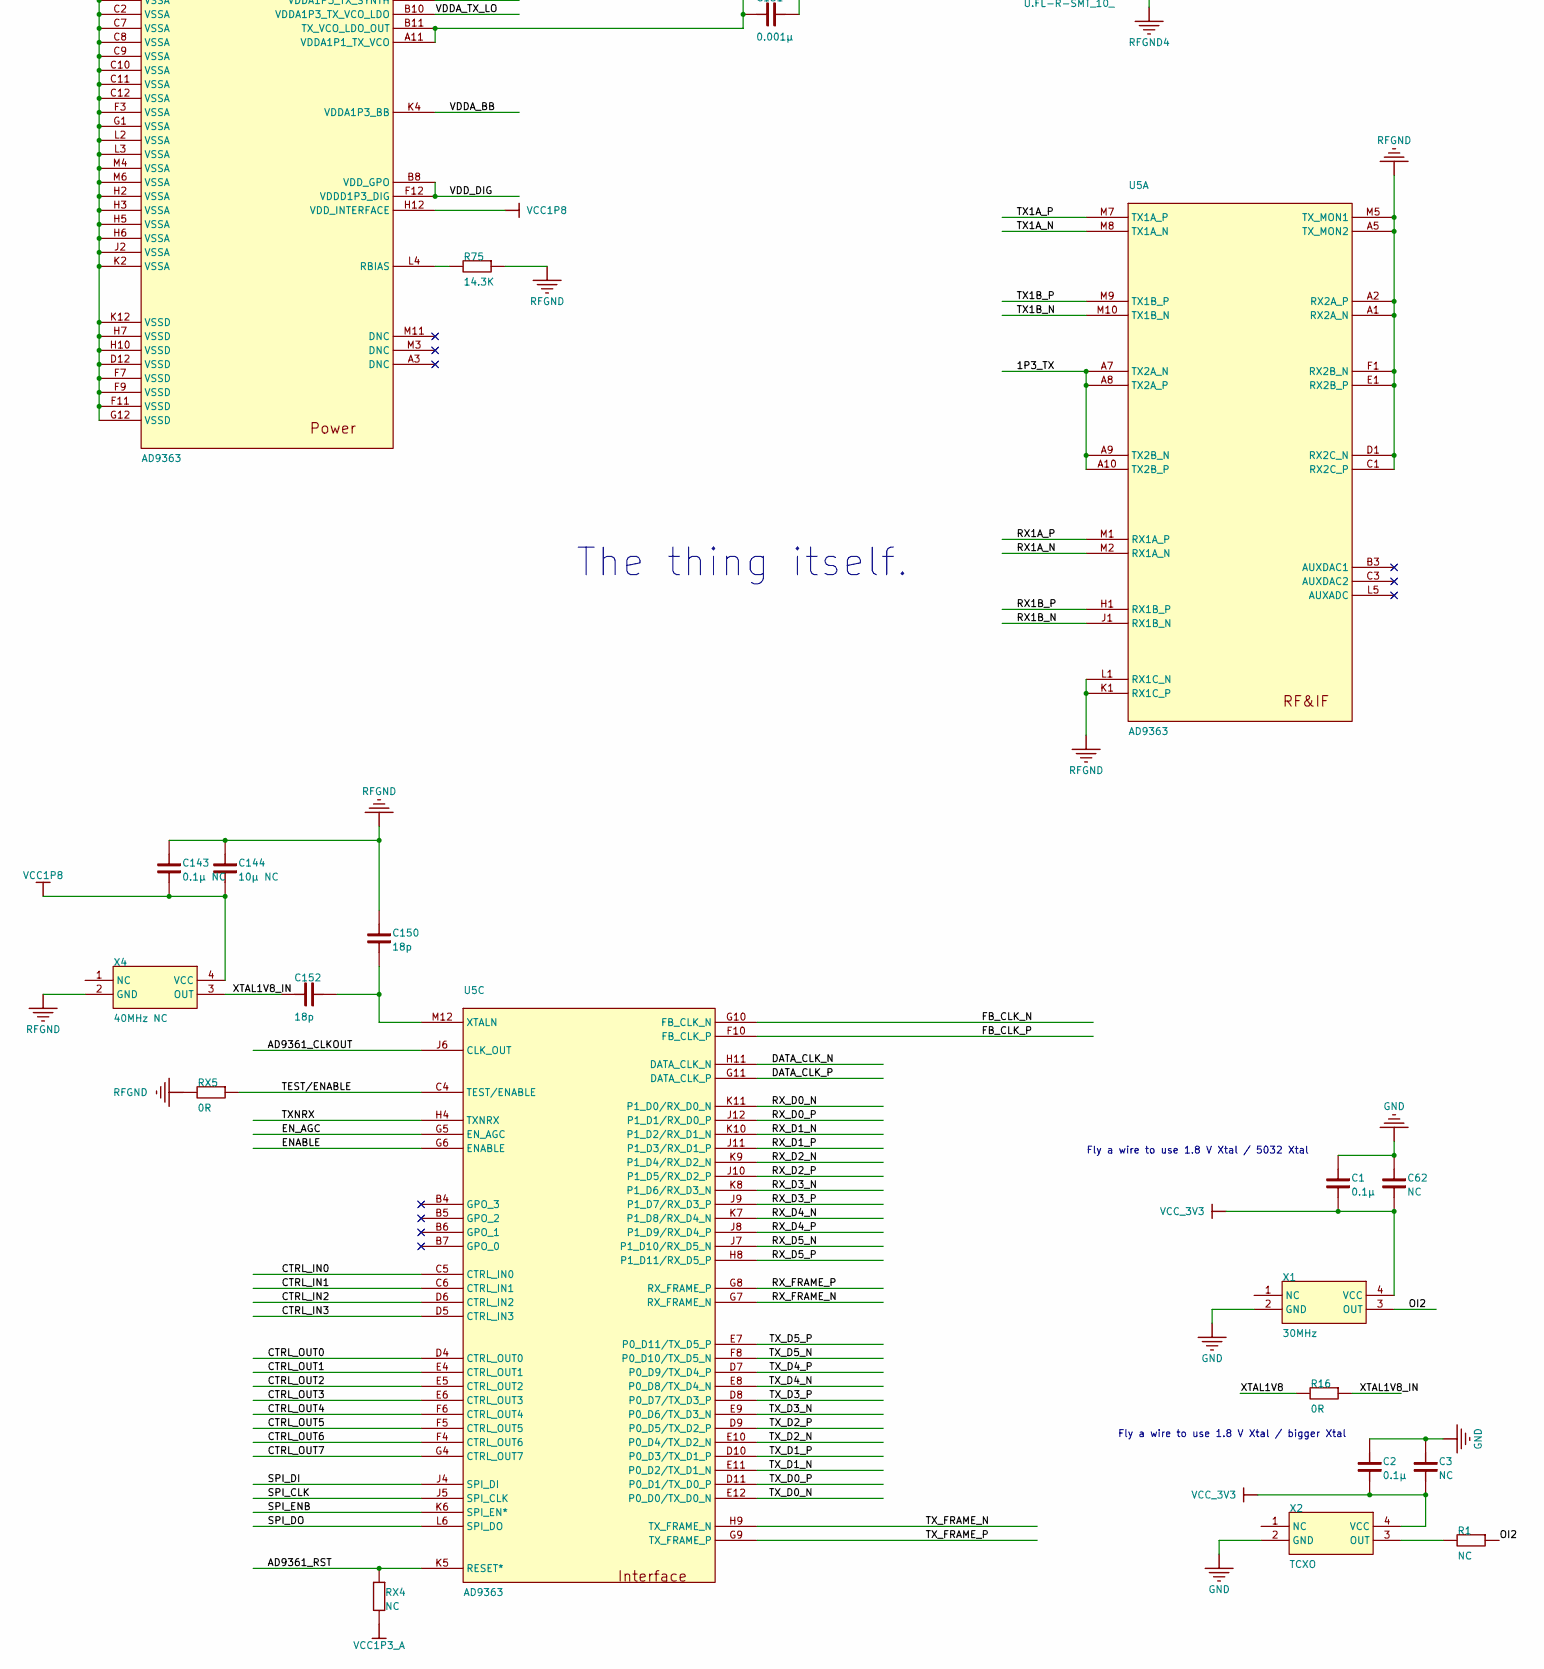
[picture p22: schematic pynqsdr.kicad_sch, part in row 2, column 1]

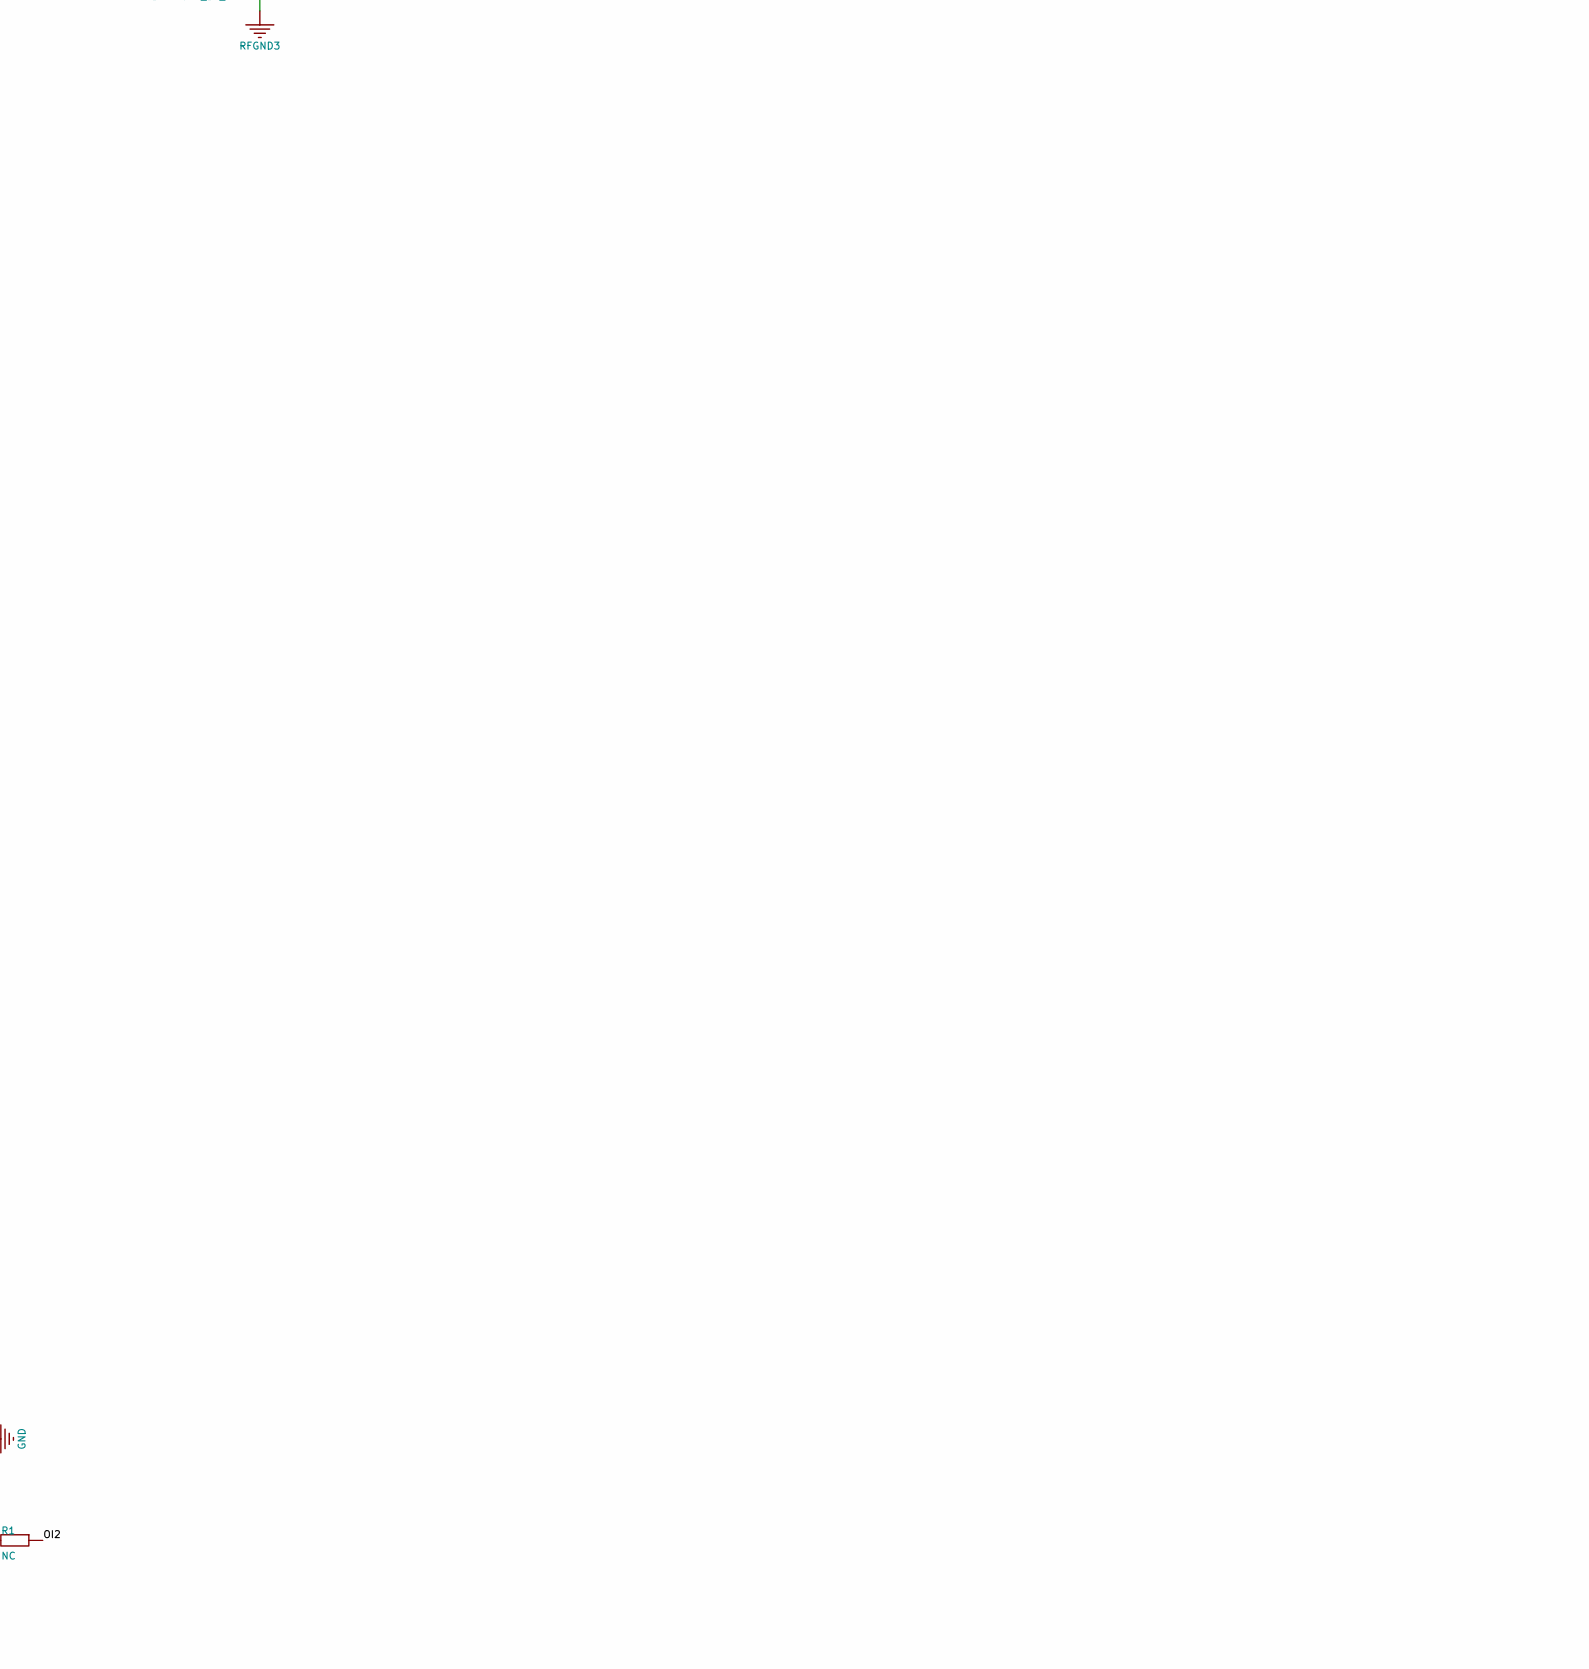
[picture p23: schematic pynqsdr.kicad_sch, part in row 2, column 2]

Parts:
1V8G1, 3V3G1, 5V0G1: Header 2; HDR1X2
7020to9363_8, 9363to7020_8: SN74AXC8T245PWR; SOP65P640X120-24N; MANUFACTURER_PART_NUMBER SN74AXC8T245PWR; MOUSER PART NUMBER 595-SN74AXC8T245PWR
C1, C2, C4, C5, C6, C7, C8, C10, C34, C35, C36, C37, C38, C39: 0.1μ; LC-0402_C
C3, C62: NC; LC-0402_C
C16, C29, C30, C31, C32, C40, C47, C48, C150, C152: 18p; LC-0402_C
C17, C22: 2.2μF; LC-0805_C
C18, C23, C27, C28: 0.1μF; LC-0402_C
C19, C24: 3.3nF; LC-0402_C
C20, C25: 2.2μF; LC-0402_C
C21, C26: 0.1μF; LC-0805_C
C33: 1nF NC; 0805_C
C58, C60: 10μ; LC-0402_C
C59, C63, C146, C151, C175, C177: 0.001μ; LC-0402_C
C142, C145, C166, C170, C172, C174: 1μ; LC-0402_C
C143: 0.1μ NC; LC-0402_C
C144: 10μ NC; LC-0402_C
CP1, CP3: 22uF; LC-0805_C
HDMI1, HDMI2: HDMI_A
J1: Header 6X2; HDR2X6
J2J3: Header 4X2; HDR2X8
J4: Header 8X2; HDR2X8
J7: Header 8; HDR1X8
L5, L7, L8, L9: 330nh; LC-0603_L
LP1: 4.7uH; L1008
PMODA1: Header 6X2; HDR2X6
PMODB1: Header 6X2; HDR2X6
R1: NC; LC-0402_R
R2: 1MΩ NC; 0805_R
R3, R4, R5, R6, R19, R20, R23, R24, R25, R26, R27: 10K; LC-0402_R
R8, R9, R10, R11, R12, R13, R14, R15: 100R; LC-0402_R
R16: 0R; LC-0402_R
R21, R22: 6.25K; LC-0402_R
R73, R74: 1R; LC-0402_R
R75: 14.3K; LC-0402_R
RP1: 10K; LC-0402_R
RP2: 20K; LC-0402_R
RX1, RX3: Conn_Coaxial; SMA_Amphenol_132289_EdgeMount
RX4: NC; LC-0402_R
RX5: 0R; LC-0402_R
RX6, RX7, RX8, RX13, RX14, RX15: 0R; LC-0603_L
RX_SMT1, RX_SMT2: U.FL-R-SMT_10_; UFLRSMT10; MANUFACTURER_PART_NUMBER U.FL-R-SMT(10); MOUSER PART NUMBER 798-U.FL-R-SMT10
T1, T2, T3, T4: TCM1-63AX+; TSML150W160H160
TX1: Conn_Coaxial; SMA_Amphenol_132289_EdgeMount
TX_SMT2: U.FL-R-SMT_10_; UFLRSMT10; MANUFACTURER_PART_NUMBER U.FL-R-SMT(10); MOUSER PART NUMBER 798-U.FL-R-SMT10
U3, U4, U6, U7, U8, U9, U10, U13: sn65cml100; TSSOP-8_3x3mm_P0.65mm
U5: AD9363; AD936X
U11, U12: TPS7A8101
UP1: AP3419
X1: 30MHz; OSC-SMD_4P-L3.2-W2.5-BL
X2: TCXO; Crystal_SMD_7050-4Pin_7.0x5.0mm
X4: 40MHz NC; OSC-SMD_4P-L3.2-W2.5-BL
bydir_4_4: SN74AXC8T245PWR; SOP65P640X120-24N; MANUFACTURER_PART_NUMBER SN74AXC8T245PWR; MOUSER PART NUMBER 595-SN74AXC8T245PWR
rxi1: ipex4; UFLRSMT10; MANUFACTURER_PART_NUMBER U.FL-R-SMT(10); MOUSER PART NUMBER 798-U.FL-R-SMT10
rxi2: U.FL-R-SMT_10_; UFLRSMT10; MANUFACTURER_PART_NUMBER U.FL-R-SMT(10); MOUSER PART NUMBER 798-U.FL-R-SMT10
txi1, txi2: U.FL-R-SMT_10_; UFLRSMT10; MANUFACTURER_PART_NUMBER U.FL-R-SMT(10); MOUSER PART NUMBER 798-U.FL-R-SMT10

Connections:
/1P3_TX: C58.1, C59.2, C60.1, C63.2, L5.1, L7.1, L8.1, L9.1, U5.A7 (TX2A_N), U5.A8 (TX2A_P), U5.A9 (TX2B_N), U5.A10 (TX2B_P)
/AD9361_CLKOUT: 9363to7020_8.6 (A4), U5.J6 (CLK_OUT)
/AD9361_RST: 7020to9363_8.5 (A3), RX4.1, U5.K5 (RESET*)
/CTRL_IN0: U5.C5 (CTRL_IN0), bydir_4_4.8 (A6)
/CTRL_IN1: U5.C6 (CTRL_IN1), bydir_4_4.10 (A8)
/CTRL_IN2: U5.D6 (CTRL_IN2), bydir_4_4.9 (A7)
/CTRL_IN3: U5.D5 (CTRL_IN3), bydir_4_4.7 (A5)
/CTRL_OUT0: 9363to7020_8.7 (A5), U5.D4 (CTRL_OUT0)
/CTRL_OUT1: U5.E4 (CTRL_OUT1), bydir_4_4.6 (A4)
/CTRL_OUT2: U5.E5 (CTRL_OUT2), bydir_4_4.5 (A3)
/CTRL_OUT3: U5.E6 (CTRL_OUT3), bydir_4_4.4 (A2)
/CTRL_OUT4: 9363to7020_8.8 (A6), U5.F6 (CTRL_OUT4)
/CTRL_OUT5: 9363to7020_8.5 (A3), U5.F5 (CTRL_OUT5)
/CTRL_OUT6: 9363to7020_8.3 (A1), U5.F4 (CTRL_OUT6)
/CTRL_OUT7: 9363to7020_8.4 (A2), U5.G4 (CTRL_OUT7)
/DATA_CLK_N: R9.2, U4.3 (B), U5.H11 (DATA_CLK_N)
/DATA_CLK_P: R9.1, U4.2 (A), U5.G11 (DATA_CLK_P)
/ENABLE: 7020to9363_8.4 (A2), U5.G6 (ENABLE)
/EN_AGC: 7020to9363_8.6 (A4), U5.G5 (EN_AGC)
/FB_CLK_N: PMODB1.7, U5.G10 (FB_CLK_N)
/FB_CLK_P: PMODB1.5, U5.F10 (FB_CLK_P)
/IO1: J2J3.1, bydir_4_4.20 (B2)
/IO2: J2J3.2, bydir_4_4.21 (B1)
/IO3: J2J3.3, bydir_4_4.18 (B4)
/IO4: J2J3.4, bydir_4_4.19 (B3)
/IO5: J2J3.5, bydir_4_4.17 (B5)
/IO6: J2J3.6, bydir_4_4.16 (B6)
/IO7: J2J3.7, bydir_4_4.15 (B7)
/IO8: J2J3.8, bydir_4_4.14 (B8)
/OI1: 7020to9363_8.20 (B2), J4.1
/OI2: 7020to9363_8.21 (B1), J4.2, R1.1, X1.3 (OUT)
/OI3: 7020to9363_8.18 (B4), J4.3
/OI4: 7020to9363_8.19 (B3), J4.4
/OI5: 7020to9363_8.17 (B5), J4.5
/OI6: 7020to9363_8.16 (B6), J4.6
/OI7: 7020to9363_8.15 (B7), J4.7
/OI8: 7020to9363_8.14 (B8), J4.8
/OI9: 9363to7020_8.14 (B8), J4.9
/OI10: 9363to7020_8.15 (B7), J4.10
/OI11: 9363to7020_8.16 (B6), J4.11
/OI12: 9363to7020_8.17 (B5), J4.12
/OI13: 9363to7020_8.18 (B4), J4.13
/OI14: 9363to7020_8.19 (B3), J4.14
/OI15: 9363to7020_8.20 (B2), J4.15
/OI16: 9363to7020_8.21 (B1), J4.16
/P1_N: PMODA1.3, U5.E9 (P0_D6/TX_D3_N)
/P1_P: PMODA1.1, U5.D8 (P0_D7/TX_D3_P)
/P2_N: PMODA1.4, U5.F8 (P0_D10/TX_D5_N)
/P2_P: PMODA1.2, U5.E7 (P0_D11/TX_D5_P)
/P3_N: PMODA1.7, U5.E11 (P0_D2/TX_D1_N)
/P3_P: PMODA1.5, U5.D10 (P0_D3/TX_D1_P)
/P4_N: PMODA1.8, U5.E12 (P0_D0/TX_D0_N)
/P4_P: PMODA1.6, U5.D11 (P0_D1/TX_D0_P)
/Q1_N: PMODB1.3, U5.H9 (TX_FRAME_N)
/Q1_P: PMODB1.1, U5.G9 (TX_FRAME_P)
/Q2_N: PMODB1.4, U5.E10 (P0_D4/TX_D2_N)
/Q2_P: PMODB1.2, U5.D9 (P0_D5/TX_D2_P)
/Q4_N: PMODB1.8, U5.E8 (P0_D8/TX_D4_N)
/Q4_P: PMODB1.6, U5.D7 (P0_D9/TX_D4_P)
/RX1AN_N: C16.1, T1.6 (SECONDARY-DOT)
/RX1AN_P: C30.1, T1.4 (SECONDARY)
/RX1A_N: C16.2, U5.M2 (RX1A_N)
/RX1A_P: C30.2, U5.M1 (RX1A_P)
/RX1BN_N: C29.1, T2.6 (SECONDARY-DOT)
/RX1BN_P: C31.1, T2.4 (SECONDARY)
/RX1B_N: C29.2, U5.J1 (RX1B_N)
/RX1B_P: C31.2, U5.H1 (RX1B_P)
/RX_D0_N: R13.2, U5.K11 (P1_D0/RX_D0_N), U9.3 (B)
/RX_D0_P: R13.1, U5.J12 (P1_D1/RX_D0_P), U9.2 (A)
/RX_D1_N: R8.2, U3.3 (B), U5.K10 (P1_D2/RX_D1_N)
/RX_D1_P: R8.1, U3.2 (A), U5.J11 (P1_D3/RX_D1_P)
/RX_D2_N: R15.2, U5.K9 (P1_D4/RX_D2_N), U13.3 (B)
/RX_D2_P: R15.1, U5.J10 (P1_D5/RX_D2_P), U13.2 (A)
/RX_D3_N: R10.2, U5.K8 (P1_D6/RX_D3_N), U6.3 (B)
/RX_D3_P: R10.1, U5.J9 (P1_D7/RX_D3_P), U6.2 (A)
/RX_D4_N: R12.2, U5.K7 (P1_D8/RX_D4_N), U8.3 (B)
/RX_D4_P: R12.1, U5.J8 (P1_D9/RX_D4_P), U8.2 (A)
/RX_D5_N: R14.2, U5.J7 (P1_D10/RX_D5_N), U10.3 (B)
/RX_D5_P: R14.1, U5.H8 (P1_D11/RX_D5_P), U10.2 (A)
/RX_FRAME_N: R11.2, U5.G7 (RX_FRAME_N), U7.3 (B)
/RX_FRAME_P: R11.1, U5.G8 (RX_FRAME_P), U7.2 (A)
/SPI_CLK: 7020to9363_8.7 (A5), U5.J5 (SPI_CLK)
/SPI_DI: 7020to9363_8.9 (A7), U5.J4 (SPI_DI)
/SPI_DO: U5.L6 (SPI_DO), bydir_4_4.3 (A1)
/SPI_ENB: 7020to9363_8.8 (A6), U5.K6 (SPI_EN*)
/TEST/ENABLE: RX5.2, U5.C4 (TEST/ENABLE)
/TMDS_CLK_N: HDMI1.12 (CLK-), U4.6 (Z)
/TMDS_CLK_P: HDMI1.10 (CLK+), U4.7 (Y)
/TMDS_D0_N: HDMI2.6 (DATA1-), U9.6 (Z)
/TMDS_D0_P: HDMI2.4 (DATA1+), U9.7 (Y)
/TMDS_D1_N: HDMI1.6 (DATA1-), U3.6 (Z)
/TMDS_D1_P: HDMI1.4 (DATA1+), U3.7 (Y)
/TMDS_D2_N: HDMI2.12 (CLK-), U13.6 (Z)
/TMDS_D2_P: HDMI2.10 (CLK+), U13.7 (Y)
/TMDS_D3_N: HDMI1.3 (DATA2-), U6.6 (Z)
/TMDS_D3_P: HDMI1.1 (DATA2+), U6.7 (Y)
/TMDS_D4_N: HDMI2.9 (DATA0-), U8.6 (Z)
/TMDS_D4_P: HDMI2.7 (DATA0+), U8.7 (Y)
/TMDS_D5_N: HDMI2.3 (DATA2-), U10.6 (Z)
/TMDS_D5_P: HDMI2.1 (DATA2+), U10.7 (Y)
/TMDS_FRAME_N: HDMI1.9 (DATA0-), U7.6 (Z)
/TMDS_FRAME_P: HDMI1.7 (DATA0+), U7.7 (Y)
/TX1AN_N: C48.2, T4.6 (SECONDARY-DOT)
/TX1AN_P: C40.2, T4.4 (SECONDARY)
/TX1A_N: C48.1, L9.2, U5.M8 (TX1A_N)
/TX1A_P: C40.1, L8.2, U5.M7 (TX1A_P)
/TX1BN_N: C47.2, T3.6 (SECONDARY-DOT)
/TX1BN_P: C32.2, T3.4 (SECONDARY)
/TX1B_N: C47.1, L7.2, U5.M10 (TX1B_N)
/TX1B_P: C32.1, L5.2, U5.M9 (TX1B_P)
/TXNRX: 7020to9363_8.10 (A8), U5.H4 (TXNRX)
/XTAL1V8: 7020to9363_8.3 (A1), R16.2
/XTAL1V8_IN: C152.2, R16.1, X4.3 (OUT)
GND: 1V8G1.2, 3V3G1.2, 5V0G1.2, 7020to9363_8.12 (GND_1), 7020to9363_8.13 (GND_2), 9363to7020_8.12 (GND_1), 9363to7020_8.13 (GND_2), C1.1, C2.1, C3.1, C4.2, C5.2, C6.2, C7.2, C8.2, C10.2, C33.2, C34.1, C35.1, C36.1, C37.1, C38.1, C39.1, C62.1, CP1.1, CP3.1, HDMI1.2 (D2_SHIELD), HDMI1.5 (D1_SHIELD), HDMI1.8 (D0_SHIELD), HDMI1.11 (CK_SHIELD), HDMI1.17 (DDC_GND), HDMI2.2 (D2_SHIELD), HDMI2.5 (D1_SHIELD), HDMI2.8 (D0_SHIELD), HDMI2.11 (CK_SHIELD), HDMI2.17 (DDC_GND), J7.6, J7.7, PMODA1.9, PMODA1.10, PMODB1.9, PMODB1.10, R2.2, R4.1, R5.2, R6.2, R19.1, R20.2, R26.1, RP1.2, RX6.2, RX7.2, RX8.2, RX13.2, RX14.2, RX15.2, U3.5 (GND), U4.5 (GND), U6.5 (GND), U7.5 (GND), U8.5 (GND), U9.5 (GND), U10.5 (GND), U13.5 (GND), UP1.2 (GND), X1.2 (GND), X2.2 (GND), bydir_4_4.12 (GND_1), bydir_4_4.13 (GND_2)
unnamed: 7020to9363_8.2 (DIR1), R6.1
unnamed: 7020to9363_8.11 (DIR2), R20.1
unnamed: 7020to9363_8.22 (OE), R19.2
unnamed: 9363to7020_8.2 (DIR1), R3.1
unnamed: 9363to7020_8.11 (DIR2), R5.1
unnamed: 9363to7020_8.22 (OE), R4.2
unnamed: C19.1, R21.2, R24.1, U11.3 (FB)
unnamed: C24.1, R22.2, R25.1, U12.3 (FB)
unnamed: C27.2, U11.6 (NR)
unnamed: C28.2, U12.6 (NR)
unnamed: C33.1, HDMI1.SH1, HDMI1.SH2, HDMI1.SH3, HDMI1.SH4, HDMI2.SH1, HDMI2.SH2, HDMI2.SH3, HDMI2.SH4, R2.1
unnamed: C142.1, R73.2
unnamed: C145.2, R74.1
unnamed: C146.2, R73.1, U5.G2 (RX_VCO_LDO_OUT), U5.G3 (VDDA1P1_RX_VCO)
unnamed: C150.2, C152.1, U5.M12 (XTALN)
unnamed: C151.2, R74.2, U5.A11 (VDDA1P1_TX_VCO), U5.B11 (TX_VCO_LDO_OUT)
unnamed: LP1.1, UP1.3 (LX)
unnamed: R1.2, X2.3 (OUT)
unnamed: R23.1, bydir_4_4.2 (DIR1)
unnamed: R26.2, bydir_4_4.22 (OE)
unnamed: R27.1, bydir_4_4.11 (DIR2)
unnamed: R75.1, U5.L4 (RBIAS)
unnamed: RP1.1, RP2.2, UP1.6 (FB)
unnamed: RX1.1 (In), RX_SMT2.3 (SIG)
unnamed: RX3.1 (In), RX_SMT1.3 (SIG)
unnamed: T1.3 (PRIMARY_DOT), rxi1.3 (SIG)
unnamed: T2.3 (PRIMARY_DOT), rxi2.3 (SIG)
unnamed: T3.3 (PRIMARY_DOT), txi1.3 (SIG)
unnamed: T4.3 (PRIMARY_DOT), txi2.3 (SIG)
unnamed: TX1.1 (In), TX_SMT2.3 (SIG)
RFGND: C17.1, C18.1, C20.1, C21.1, C22.1, C23.1, C25.1, C26.1, C27.1, C28.1, C58.2, C59.1, C60.2, C63.1, C142.2, C143.1, C144.1, C145.1, C146.1, C150.1, C151.1, C166.2, C170.2, C172.2, C174.2, C175.2, C177.2, R24.2, R25.2, R75.2, RX5.1, RX6.1, RX7.1, RX8.1, RX13.1, RX14.1, RX15.1, T1.1 (NOT_USED), T1.2 (PRIMARY), T1.5 (NOT_USED), T2.1 (NOT_USED), T2.2 (PRIMARY), T2.5 (NOT_USED), T3.1 (NOT_USED), T3.2 (PRIMARY), T3.5 (NOT_USED), T4.1 (NOT_USED), T4.2 (PRIMARY), T4.5 (NOT_USED), U5.A1 (RX2A_N), U5.A2 (RX2A_P), U5.A4 (VSSA), U5.A5 (TX_MON2), U5.A6 (VSSA), U5.A12 (VSSA), U5.B1 (VSSA), U5.B2 (VSSA), U5.B12 (VSSA), U5.C1 (RX2C_P), U5.C2 (VSSA), U5.C7 (VSSA), U5.C8 (VSSA), U5.C9 (VSSA), U5.C10 (VSSA), U5.C11 (VSSA), U5.C12 (VSSA), U5.D1 (RX2C_N), U5.D12 (VSSD), U5.E1 (RX2B_P), U5.F1 (RX2B_N), U5.F3 (VSSA), U5.F7 (VSSD), U5.F9 (VSSD), U5.F11 (VSSD), U5.G1 (VSSA), U5.G12 (VSSD), U5.H2 (VSSA), U5.H3 (VSSA), U5.H5 (VSSA), U5.H6 (VSSA), U5.H7 (VSSD), U5.H10 (VSSD), U5.J2 (VSSA), U5.K1 (RX1C_P), U5.K2 (VSSA), U5.K12 (VSSD), U5.L1 (RX1C_N), U5.L2 (VSSA), U5.L3 (VSSA), U5.L7 (VSSA), U5.L8 (VSSA), U5.L9 (VSSA), U5.L10 (VSSA), U5.L11 (VSSA), U5.L12 (VSSA), U5.M4 (VSSA), U5.M5 (TX_MON1), U5.M6 (VSSA), U11.0 (EPAD), U11.4 (GND), U12.0 (EPAD), U12.4 (GND), X4.2 (GND), rxi1.1 (GND_1), rxi1.2 (GND_2), rxi2.1 (GND_1), rxi2.2 (GND_2), txi1.1 (GND_1), txi1.2 (GND_2), txi2.1 (GND_1), txi2.2 (GND_2)
RFGND2: RX3.2 (Ext), RX_SMT1.1 (GND_1), RX_SMT1.2 (GND_2)
RFGND3: RX1.2 (Ext), RX_SMT2.1 (GND_1), RX_SMT2.2 (GND_2)
RFGND4: TX1.2 (Ext), TX_SMT2.1 (GND_1), TX_SMT2.2 (GND_2)
VCC1P3_A: C22.2, C23.2, C24.2, C172.1, C177.1, R22.1, RX4.2, U5.B8 (VDD_GPO), U5.D2 (VDDA1P3_RX_RF), U5.D3 (VDDA1P3_RX_TX), U5.E3 (VDDA1P3_TX_LO_BUFFER), U5.F12 (VDDD1P3_DIG), U5.K4 (VDDA1P3_BB), U12.1 (OUT), U12.2 (OUT)
VCC1P3_B: C17.2, C18.2, C19.2, C166.1, C170.1, C174.1, C175.1, R21.1, U5.B9 (VDDA1P3_TX_LO), U5.B10 (VDDA1P3_TX_VCO_LDO), U5.E2 (VDDA1P3_RX_LO), U5.F2 (VDDA1P3_RX_VCO_LDO), U5.J3 (VDDA1P3_RX_SYNTH), U5.K3 (VDDA1P3_TX_SYNTH), U11.1 (OUT), U11.2 (OUT)
VCC1P8: 1V8G1.1, 7020to9363_8.1 (VCCA), 9363to7020_8.1 (VCCA), C34.2, C36.2, C38.2, C143.2, C144.2, CP3.2, LP1.2, R3.2, R23.2, R27.2, RP2.1, U5.H12 (VDD_INTERFACE), X4.4 (VCC), bydir_4_4.1 (VCCA)
VCC_3V3: 3V3G1.1, 7020to9363_8.23 (VCCB_1), 7020to9363_8.24 (VCCB_2), 9363to7020_8.23 (VCCB_1), 9363to7020_8.24 (VCCB_2), C1.2, C2.2, C3.2, C4.1, C5.1, C6.1, C7.1, C8.1, C10.1, C20.2, C21.2, C25.2, C26.2, C35.2, C37.2, C39.2, C62.2, CP1.2, J7.4, PMODA1.11, PMODA1.12, PMODB1.11, PMODB1.12, U3.8 (Vcc), U4.8 (Vcc), U6.8 (Vcc), U7.8 (Vcc), U8.8 (Vcc), U9.8 (Vcc), U10.8 (Vcc), U11.5 (EN), U11.7 (IN), U11.8 (IN), U12.5 (EN), U12.7 (IN), U12.8 (IN), U13.8 (Vcc), UP1.1 (EN), UP1.4 (VIN), X1.4 (VCC), X2.4 (VCC), bydir_4_4.23 (VCCB_1), bydir_4_4.24 (VCCB_2)
VCC_5V0: 5V0G1.1, J7.5

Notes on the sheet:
Digital interface 1.8V
IPEX and SMA connectors
Fly a wire to use 1.8 V Xtal / 5032 Xtal
LVDS RX
Level converters
Fly a wire to use 1.8 V Xtal / bigger Xtal
-->
The thing itself.
LVDS TX
RF Power 1.3V
Connectors to PYNQ

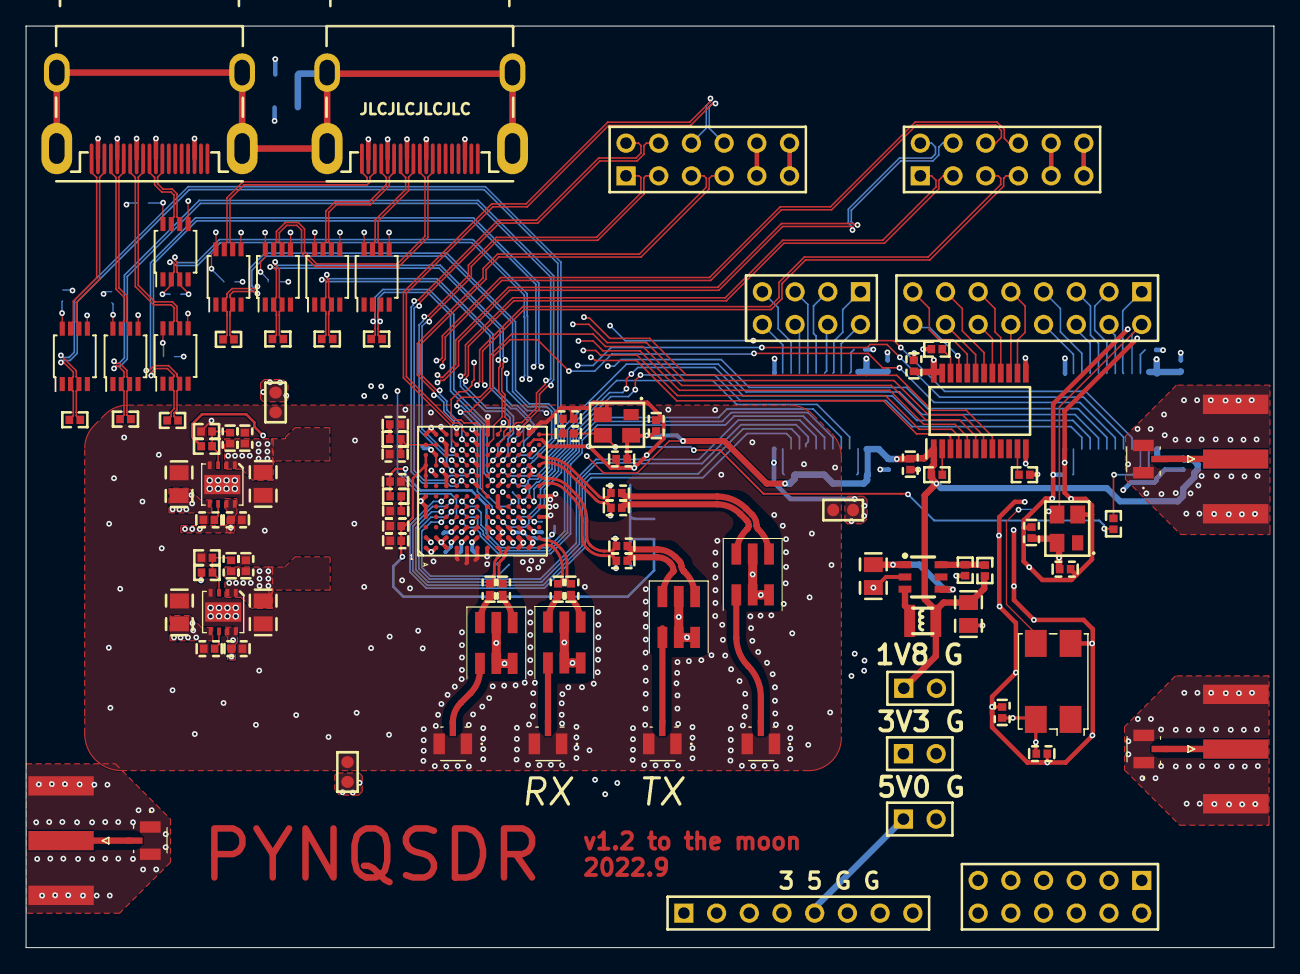
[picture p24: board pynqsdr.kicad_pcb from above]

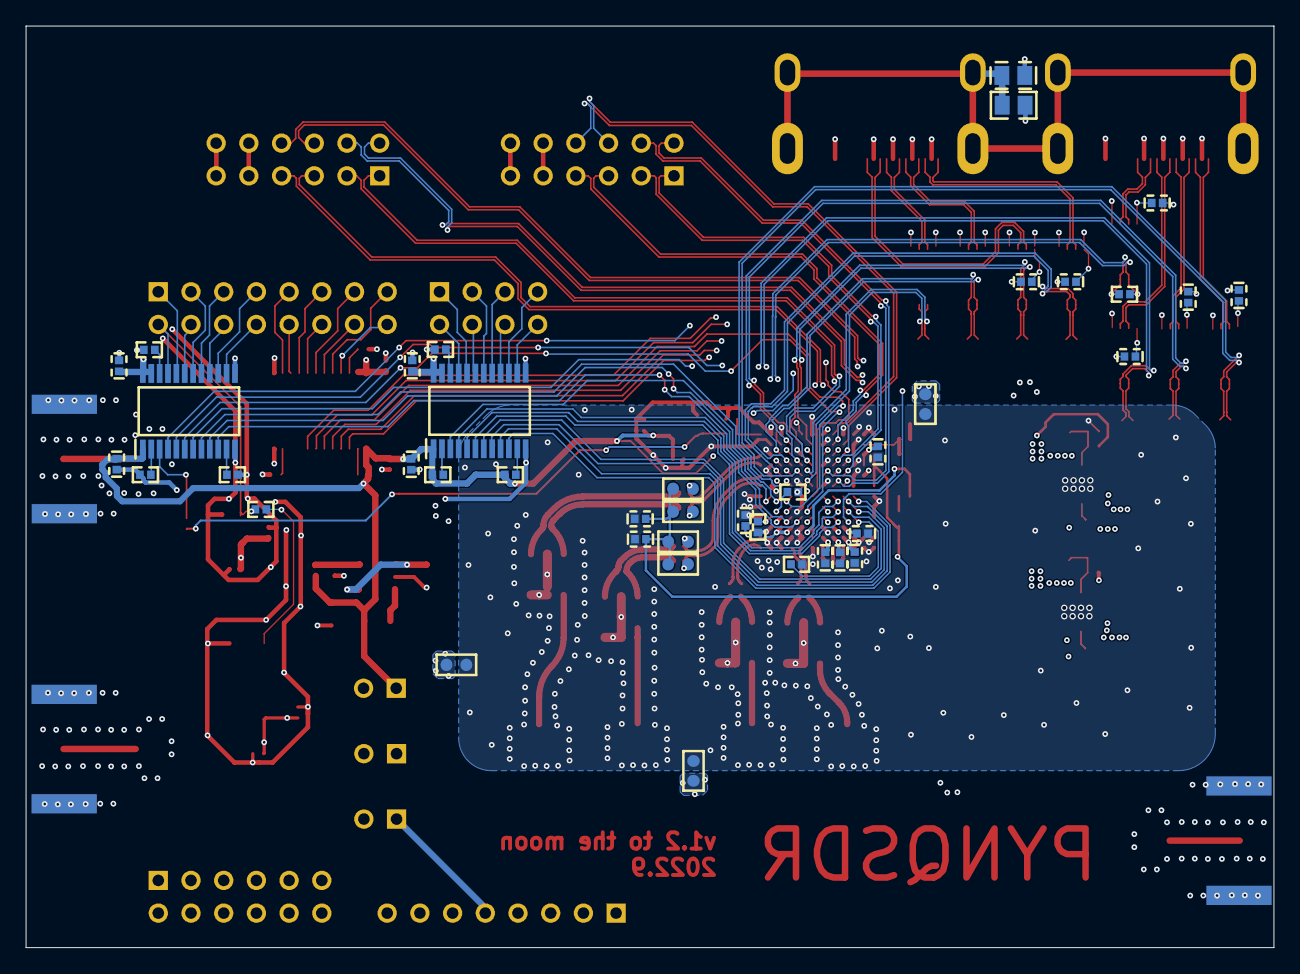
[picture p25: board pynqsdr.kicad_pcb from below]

Board: 4 copper layers, 96.9 x 71.6 mm, 142 parts (40 on the bottom side), 153 nets.

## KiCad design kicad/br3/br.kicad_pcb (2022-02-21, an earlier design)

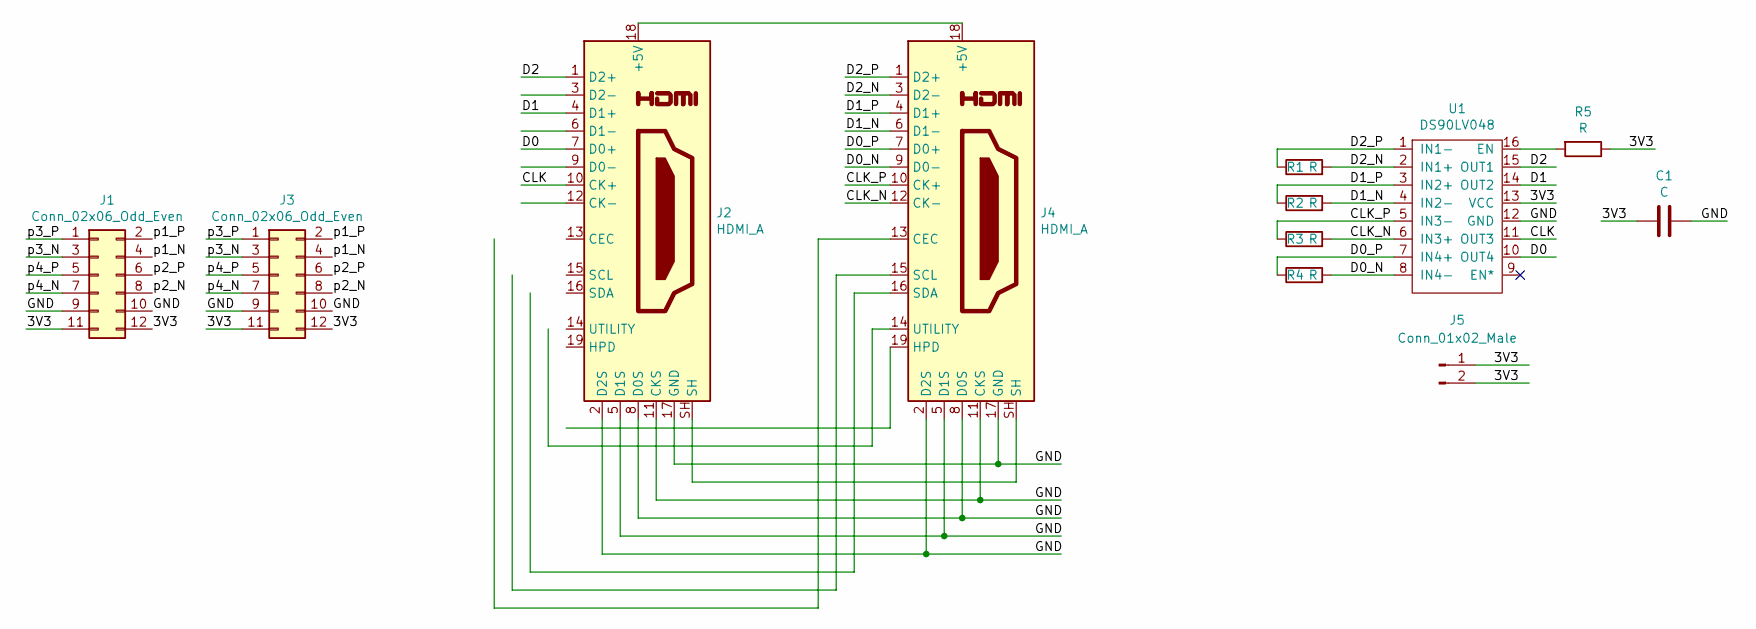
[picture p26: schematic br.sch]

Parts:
C1: C; C_0603_1608Metric_Pad1.08x0.95mm_HandSolder
J1, J3: Conn_02x06_Odd_Even; PinHeader_2x06_P2.54mm_Vertical
J2, J4: HDMI_A; HDMI_A_Kycon_KDMIX-SL1-NS-WS-B15_VerticalRightAngle
J5: Conn_01x02_Male; PinHeader_1x02_P2.54mm_Vertical
R1, R2, R3, R4, R5: R; R_0402_1005Metric_Pad0.72x0.64mm_HandSolder
U1: DS90LV048; SOIC-16_3.9x9.9mm_P1.27mm

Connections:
/3V3: C1.1, J1.11, J1.12, J3.11, J3.12, J5.1, J5.2, R5.1, U1.13 (VCC)
/CLK: J2.10 (CK+), U1.11 (OUT3)
/CLK_N: J4.12 (CK-), R3.2, U1.6 (IN3+)
/CLK_P: J4.10 (CK+), R3.1, U1.5 (IN3-)
/D0: J2.7 (D0+), U1.10 (OUT4)
/D0_N: J4.9 (D0-), R4.2, U1.8 (IN4-)
/D0_P: J4.7 (D0+), R4.1, U1.7 (IN4+)
/D1: J2.4 (D1+), U1.14 (OUT2)
/D1_N: J4.6 (D1-), R2.2, U1.4 (IN2-)
/D1_P: J4.4 (D1+), R2.1, U1.3 (IN2+)
/D2: J2.1 (D2+), U1.15 (OUT1)
/D2_N: J4.3 (D2-), R1.2, U1.2 (IN1+)
/D2_P: J4.1 (D2+), R1.1, U1.1 (IN1-)
/GND: C1.2, J1.9, J1.10, J2.2 (D2S), J2.5 (D1S), J2.8 (D0S), J2.11 (CKS), J2.17 (GND), J3.9, J3.10, J4.2 (D2S), J4.5 (D1S), J4.8 (D0S), J4.11 (CKS), J4.17 (GND), U1.12 (GND)
/p1_N: J1.4, J3.4
/p1_P: J1.2, J3.2
/p2_N: J1.8, J3.8
/p2_P: J1.6, J3.6
/p3_N: J1.3, J3.3
/p3_P: J1.1, J3.1
/p4_N: J1.7, J3.7
/p4_P: J1.5, J3.5
unnamed: J2.18 (+5V), J4.18 (+5V)
unnamed: J2.SH, J4.SH
unnamed: R5.2, U1.16 (EN)

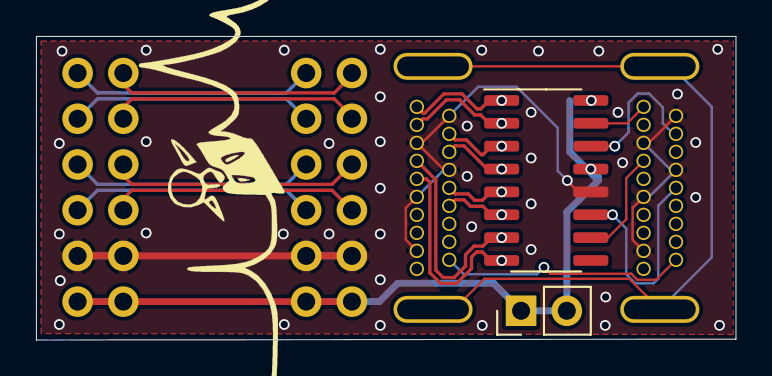
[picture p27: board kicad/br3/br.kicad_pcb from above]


Board: 2 copper layers, 38.9 x 16.9 mm, 12 parts (6 on the bottom side), 25 nets.

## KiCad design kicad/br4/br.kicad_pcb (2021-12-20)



Board: 2 copper layers, 38.9 x 16.9 mm, 15 parts (5 on the bottom side), 28 nets.

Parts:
C1, C2: C; C_0603_1608Metric_Pad1.08x0.95mm_HandSolder
J1, J3: Conn_02x06_Odd_Even; PinHeader_2x06_P2.54mm_Vertical
J2, J4: HDMI_A; HDMI_A_Kycon_KDMIX-SL1-NS-WS-B15_VerticalRightAngle
J5: Conn_01x02_Male; PinHeader_1x02_P2.54mm_Vertical
R1, R2, R3, R4: R; R_0402_1005Metric_Pad0.72x0.64mm_HandSolder
U1, U2, U3, U4: SN65CML100; TSSOP-8_4.4x3mm_P0.65mm

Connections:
/3V3: C1.1, C2.1, J1.11, J1.12, J3.11, J3.12, J5.1, J5.2, U1.8, U2.8, U3.8, U4.8
/CLK_N: J4.12, R3.2, U3.3
/CLK_P: J4.10, R3.1, U3.2
/CLK_TMDS_N: J2.12, U3.6
/CLK_TMDS_P: J2.10, U3.7
/D0_N: J4.9, R4.2, U4.3
/D0_P: J4.7, R4.1, U4.2
/D0_TMDS_N: J2.9, U4.6
/D0_TMDS_P: J2.7, U4.7
/D1_N: J4.6, R2.1, U2.2
/D1_P: J4.4, R2.2, U2.3
/D1_TMDS_N: J2.6, U2.7
/D1_TMDS_P: J2.4, U2.6
/D2_N: J4.3, R1.2, U1.3
/D2_P: J4.1, R1.1, U1.2
/D2_TMDS_N: J2.3, U1.6
/D2_TMDS_P: J2.1, U1.7
/GND: C1.2, C2.2, J1.9, J1.10, J2.2, J2.5, J2.8, J2.11, J2.17, J3.9, J3.10, J4.2, J4.5, J4.8, J4.11, J4.17, U1.5, U2.5, U3.5, U4.5
/p1_N: J1.4, J3.4
/p1_P: J1.2, J3.2
/p2_N: J1.8, J3.8
/p2_P: J1.6, J3.6
/p3_N: J1.3, J3.3
/p3_P: J1.1, J3.1
/p4_N: J1.7, J3.7
/p4_P: J1.5, J3.5
unnamed: J2.18, J4.18
unnamed: J2.SH, J4.SH

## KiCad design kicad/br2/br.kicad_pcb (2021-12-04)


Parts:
C1: C; C_0603_1608Metric_Pad1.08x0.95mm_HandSolder
D1: LED; LED_0603_1608Metric_Pad1.05x0.95mm_HandSolder
J1, J3: Conn_02x06_Odd_Even; PinHeader_2x06_P2.54mm_Vertical
R1, R2, R4, R5, R6: R; R_0402_1005Metric_Pad0.72x0.64mm_HandSolder
R3: 330; R_0603_1608Metric_Pad0.98x0.95mm_HandSolder
U1: SN65LVDS047D; SOIC-16_3.9x9.9mm_P1.27mm

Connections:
/3V3: C1.1, J1.11, J1.12, J3.11, J3.12, R3.2, R6.2, U1.4 (VCC)
/GND: C1.2, D1.1 (K), J1.9, J1.10, J3.9, J3.10, R1.2, R2.2, R4.1, R5.1, U1.5 (GND)
/p1: J1.1, U1.7 (DIN4)
/p1_N: J3.3, U1.10 (DOUT4+)
/p1_P: J3.1, U1.9 (DOUT4-)
/p2: J1.5, U1.3 (DIN2)
/p2_N: J3.7, U1.14 (DOUT2+)
/p2_P: J3.5, U1.13 (DOUT2-)
/p3: J1.4, U1.6 (DIN3)
/p3_N: J3.4, U1.12 (DOUT3-)
/p3_P: J3.2, U1.11 (DOUT3+)
/p4: J1.8, U1.2 (DIN1)
/p4_N: J3.8, U1.16 (DOUT1-)
/p4_P: J3.6, U1.15 (DOUT1+)
unnamed: D1.2 (A), R3.1
unnamed: J1.2, R4.2
unnamed: J1.3, R1.1
unnamed: J1.6, R5.2
unnamed: J1.7, R2.1
unnamed: R6.1, U1.1 (EN)

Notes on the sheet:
This is intentional



Board: 2 copper layers, 20.3 x 17.6 mm, 11 parts (5 on the bottom side), 20 nets.

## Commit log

2021-12-04 Board files release
    [br.kicad_pcb, br.sch, pynqsdr.kicad_pcb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]
2021-12-20 V0.9 release and document update
    [br.kicad_pcb, br.sch]
2022-02-21 Clean up old files a littel bit
    [br.kicad_pcb, br.kicad_sch, br.sch]
2022-02-21 v1.1 update
    [pynqsdr.kicad_pcb, pynqsdr.kicad_sch]
2022-10-28 V1.2 update
    [br.kicad_pcb, br.kicad_sch, pynqsdr.kicad_pcb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]
2022-11-03 Added first try of ebazsdr
    [ebaz_sdr.kicad_pcb, ebaz_sdr.kicad_sch]
